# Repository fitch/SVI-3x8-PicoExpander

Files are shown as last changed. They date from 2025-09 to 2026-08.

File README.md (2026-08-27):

# SVI-3x8 PicoExpander

## Overview

The SVI-3x8 PicoExpander is a Raspberry Pico 2 W based expansion device for Spectravideo 318 and 328 computers.

The device emulates (when plugged into the SVI-3x8 expansion port):
 - **96 kB of additional RAM (BK22, BK31, BK32) to SVI-328**, to be used for example with BASIC SWITCH command or CP/M
 - **144 kB more RAM to SVI-318**, converting it to a SVI-328 and allowing games designed for SVI-328 to be run on a 318
 - **Disk emulation (.dsk)** so you can load and save disk images via Wi-Fi
 - **Cassette drive emulation (.cas)** with auto-running, allowing you to finally send and run .CAS images via Wi-Fi
 - **Support for 64 kB ROM game cartridges**, without using the game cartridge slot and finally fixing the 64 kB ROM support in SVI-328 MKII devices
 - **Save states** to save computer state and load it at later time, making it possible to save your progress in a game and continue later
 - **Remote launch** allowing you to pick up a game image from PC/Mac and launch it from the SVI via Wi-Fi
 - **Hard disk emulation** with server-based network backing, allowing CP/M hard disk images to be served over Wi-Fi

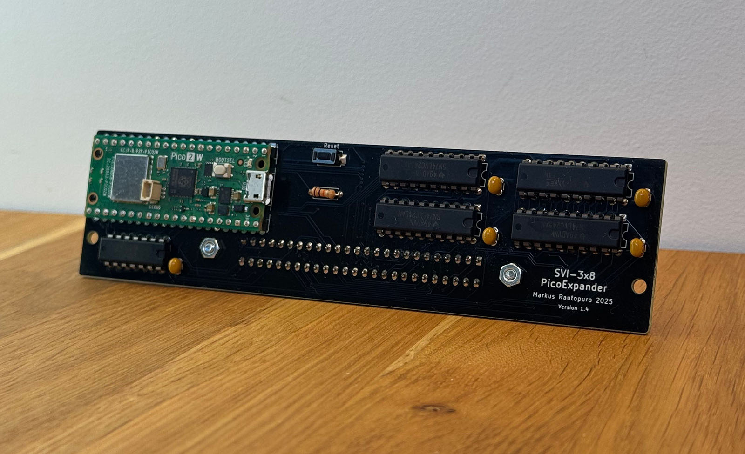
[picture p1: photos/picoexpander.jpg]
PicoExpander

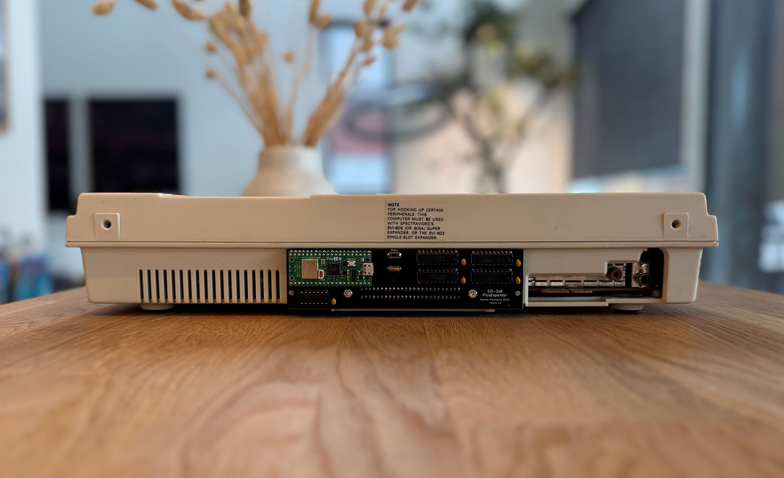
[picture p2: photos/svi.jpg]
SVI


## Limitations

Limitations of the current software (1.4.4):
 - Supports only one disk drive, two-disk drive support coming up

## The project

This repository will later include the full software and the hardware design later as open source. Now you can access the 1.4 PCB version in [pcb](pcb/) directory.

If you can't build one yourself, you can order an assembled version from [here](https://svi-328-dev.company.site/products/svi-3x8-picoexpander-1-4). Current shipping estimate in 1-4 weeks depending on the order volumes.

<b>Important note:</b>

This is ”bleeding edge” hardware, so it might not last 40 years as the SVI did. The Pico pins are used with level shifters and within the limits of the voltage thresholds, but the actual Pico CPU is running overclocked at 300 MHz (normally 150 MHz). This might cause the Pico to wear out sooner than Raspberry has designed it to. However, the Pico can be replaced on the board if needed.

Also, note that device is a prototype and therefore has very limited warranty: you can test it when it arrives and if you're not satisfied, we'll figure out if we ship a new one or you get your money back or something else. But everything else is at your own risk. If the device stops working after 3-12 months, you'll need to fix it yourself or get a new one.

## Quick Start

### 1. Flash the Firmware

When you've built the PCB you can flash the .UF2 file provided in the [release](release/) directory. For the assembled devices, the Pico has already been flashed with the latest firmware.

1. Disconnect PicoExpander from SVI
2. Hold the **BOOTSEL** button on the Pico W while connecting it to your computer via USB
3. The Pico will appear as a USB mass storage device
4. Copy the `.uf2` firmware file from the `release/` directory to the Pico USB drive. Wait until Pico disconnects (displays Disk Not Ejected Properly in macOS) and the green LED light turns on to signal that the firmware booted correctly.
5. Finally, remove the USB cable.

### 2. Install Node.js

The file server requires Node.js to run. This project includes an `.nvmrc` file specifying Node.js v22.20.0.

**macOS (using nvm):**

Install [nvm](https://github.com/nvm-sh/nvm) if you don't have it, then:
```bash
# Install and use the correct Node.js version
nvm install
nvm use
```

**Windows:**
Download and install from [nodejs.org](https://nodejs.org/)

### 3. Boot the SVI with PicoExpander

Place the PicoExpander into the expansion port of the SVI-318 or SVI-328. Boot SVI up.

You can return to the main menu in two ways:
- Press the **RESET button** on the PicoExpander briefly
- Press **CTRL + SHIFT + LEFT GRAPH + RIGHT GRAPH** simultaneously on the keyboard

If you need to reset the SVI, press the RESET button for at least 3 seconds.

### 4. Run the File Server

Start the server with a directory containing your disk images, ROMs, and cassette files:

```bash
node js/server.js ./images
```

The server will:
- Scan the directory for supported files (.rom, .dsk, .cas, .sta)
- Connect to the PicoExpander over Wi-Fi
- Serve files to the SVI-328 on demand

Press **H** in the server to see available commands.

## Documentation

For detailed documentation, see the `doc/` directory:

| Document | Description |
|---|---|
| [server.md](doc/server.md) | File server usage and interactive commands |
| [send_command.md](doc/send_command.md) | Command-line tool for scripting and automation |
| [hard-disk-emulation.md](doc/hard-disk-emulation.md) | Hard disk emulation setup and usage |
| [boot-sequence.md](doc/boot-sequence.md) | Technical details of the PicoExpander boot process |
| [io-ports.md](doc/io-ports.md) | I/O port reference for developers |
| [save-state-format.md](doc/save-state-format.md) | Save state file format specification |
| [development.md](doc/development.md) | Building the ROM and development setup |
| [pcb/README.md](pcb/README.md) | PCB design files, schematics overview, and parts list |

## Release Notes

See the latest changes in [v1.4.4 release notes](release/release-notes-1.4.4.md).

## License

Detailed licensing information is documented within the included [LICENSE](LICENSE) file.

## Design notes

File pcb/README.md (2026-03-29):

# SVI-3x8 PicoExpander PCB

## Overview

This directory contains the KiCad hardware design files for the SVI-3x8 PicoExpander and the SuperExpander adapter board.

## Projects

### PicoExpander (main board)

The main expansion board that connects to the SVI-3x8 expansion port via a 50-pin edge connector.

- **KiCad project:** [SVI-3x8-PicoExpander.kicad_pro](SVI-3x8-PicoExpander.kicad_pro)
- **Schematic:** [SVI-3x8-PicoExpander.kicad_sch](SVI-3x8-PicoExpander.kicad_sch)
- **PCB layout:** [SVI-3x8-PicoExpander.kicad_pcb](SVI-3x8-PicoExpander.kicad_pcb)
- **Schematics PDF:** [schematics.pdf](../photos/schematics.pdf)

### SuperExpander Adapter

A simple passive adapter board that allows the PicoExpander to be connected to the Spectravideo SuperExpander (SVI-605) instead of directly to the computer's expansion port.

- **KiCad project:** [SVI-3x8-PicoExpander-SuperExpander-adapter.kicad_pro](SVI-3x8-PicoExpander-SuperExpander-adapter.kicad_pro)
- **PCB layout:** [SVI-3x8-PicoExpander-SuperExpander-adapter.kicad_pcb](SVI-3x8-PicoExpander-SuperExpander-adapter.kicad_pcb)

### Gerber Files

Manufacturing-ready Gerber files are available in the [gerber/](gerber/) directory:

- [gerber/PicoExpander/](gerber/PicoExpander/) — Main board Gerbers
- [gerber/SuperExpander adapter/](gerber/SuperExpander%20adapter/) — Adapter board Gerbers

## Schematics Overview

The PicoExpander circuit consists of:

- **Raspberry Pi Pico 2 W (A1)** — The main microcontroller running the emulation firmware at 300 MHz. Connects to the SVI bus through level shifters and handles all emulation logic, Wi-Fi connectivity, and flash storage.

- **4x 74LVC245A level shifters (U1, U2, U4, U5)** — Bidirectional bus transceivers that translate between the SVI's 5V bus and the Pico's 3.3V logic levels:
  - **U5** — Data bus write (SVI → Pico, active during bus writes)
  - **U1** — Data bus read (Pico → SVI, active during bus reads)
  - **U2** — Lower address bus A0–A7
  - **U4** — Higher address bus A8–A15

- **74HC14 Schmitt trigger (U3, 7 gates used)** — Provides clean signal conditioning for active-low control signals from the SVI bus: `/RST`, `/ROMDIS`, `/RD`, `/WR`, `/MREQ`, `/P_AE` (address enable), and `/P_RD_DE`/`/P_WR_DE` (data direction enable).

- **50-pin edge connector (J1)** — Interfaces directly with the SVI-3x8 expansion bus, providing access to the full address bus, data bus, and control signals.

- **Reset button (SW1)** — Short press returns to the PicoExpander menu. Long press (3+ seconds) resets the SVI.

- **Pull-up resistor (R1, 10kΩ)** — Pull-up on the reset line.

- **Decoupling capacitors (C2–C5, 0.1μF)** — One per level shifter IC for power supply filtering.

## Parts List

| Ref | Qty | Description | DigiKey Part | DigiKey # |
|-----|-----|---|---|---|
| A1 | 1 | Raspberry Pi Pico 2 W (RP2350) | [SC1634](https://www.digikey.com/en/products/detail/raspberry-pi/SC1634/26241087) | 2648-SC1634-ND |
| U1, U2, U4, U5 | 4 | 74LVC245A — Bidirectional level shifter, 3.6V, 20-PDIP | [SN74LVC245AN](https://www.digikey.com/en/products/detail/texas-instruments/SN74LVC245AN/377483) | 296-8503-5-ND |
| U3 | 1 | 74HC14 — Hex Schmitt trigger inverter, 14-DIP | [SN74AHCT14N](https://www.digikey.com/en/products/detail/texas-instruments/SN74AHCT14N/375854) | 296-4674-5-ND |
| C2–C5 | 4 | 0.1μF ceramic capacitor, 50V, X7R, radial | [K104K15X7RF5TL2](https://www.digikey.com/en/products/detail/vishay-beyschlag-draloric-bc-components/K104K15X7RF5TL2/286538) | BC1084CT-ND |
| R1 | 1 | 10kΩ resistor, 1/4W, 1%, axial | [MFR-25FRF52-10K](https://www.digikey.com/en/products/detail/yageo/MFR-25FRF52-10K/14626) | 13-MFR-25FRF52-10KCT-ND |
| J1 | 1 | 50-pin (2x25) card edge connector, dual female, 0.100" pitch | [395-050-524-202](https://www.digikey.com/en/products/detail/edac-inc/395-050-524-202/1297302) | 395-050-524-202-ND |
| SW1 | 1 | Tactile push button switch, SPST-NO, 0.05A, 12V | [PTS636 SP43 LFS](https://www.digikey.com/product-detail/en/c-k/PTS636-SP43-LFS/CKN12304-ND/10071717) | CKN12304-ND |

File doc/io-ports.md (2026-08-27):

# I/O Ports Reference

This document describes the I/O ports used by the PicoExpander to communicate between the Z80 CPU and the Pico microcontroller.

## Table of Contents

- [Port Map Overview](#port-map-overview)
- [Pico Control Ports (0x13-0x18)](#pico-control-ports-0x13-0x18)
- [Cassette Emulation Ports (0x64-0x65)](#cassette-emulation-ports-0x64-0x65)
- [FDC Emulation Ports (0x30-0x38)](#fdc-emulation-ports-0x30-0x38)
- [Command Reference](#command-reference)
- [Appendix A: State Codes](#appendix-a-state-codes)
- [Appendix B: File Type Codes](#appendix-b-file-type-codes)
- [Appendix C: Status Response Codes](#appendix-c-status-response-codes)

---

## Port Map Overview

| Port Range  | Category | Description |
|---|---|---|
| 0x13-0x18 | Pico Control | Status, commands, data transfer, timers |
| 0x30-0x38 | FDC | Floppy disk controller emulation |
| 0x64-0x65 | Cassette | Tape emulation |
| 0x80-0x85 | VDP | Video Display Processor (see note below) |
| 0x88, 0x8C  | PSG | Programmable Sound Generator (see note below) |

> **Note:** VDP ports are used to read VDP register status for restoring the state after exiting the menu. PSG ports are read to enable preventing actual bank switching by using a fake register injection.

---

## Pico Control Ports (0x13-0x18)

### Port 0x13 - Command & Status

| Direction | Function | Description |
|---|---|---|
| Read | Pico State | Returns current Pico state (see [Appendix A](#appendix-a-state-codes)) |
| Write | Pico Command | Sends command to Pico (see [Command Reference](#command-reference)) |

### Port 0x14 - Data Transfer

| Direction | Function | Description |
|---|---|---|
| Read | Pico Data  | Reads data from Pico (context depends on last command) |
| Write | Pico Data  | Writes data to Pico (context depends on last command) |

Data format and interpretation depend on the command previously sent to port 0x13.

### Port 0x15 - Timer High Byte

| Direction | Function | Description |
|---|---|---|
| Read | Timer High | Returns high 8 bits of timestamp counter |
| Write | Timer Reset  | Resets the timestamp counter to 0 |

### Port 0x16 - Timer Low Byte

| Direction | Function | Description |
|---|---|---|
| Read | Timer Low  | Returns low 8 bits of timestamp counter |

**Timer Details:** 16-bit microsecond counter (0-65535 μs, wraps in ~65.5ms). Read 0x15 first (high byte), then 0x16 (low byte). Write any value to 0x15 to reset. Increments at 1 MHz from Pico hardware timer.

### Port 0x17 - Debug Output

| Direction | Function | Description |
|---|---|---|
| Write | Debug | Writes debug values to hardware log |

### Port 0x18 - Status Flags

| Direction | Function | Description |
|---|---|---|
| Read | Status Flags | Network, file serving, and boot status |

**Bit Layout:**
```
┌─────┬─────┬─────┬─────┬─────┬─────┬─────┬─────┐
│  7  │  6  │  5  │  4  │  3  │  2  │  1  │  0  │
├─────┼─────┼─────┴─────┴─────┼─────┴─────┴─────┤
│ RSV │BOOT │  File Status    │ Network Status  │
└─────┴─────┴─────────────────┴─────────────────┘
```

#### Bits 0-2: Network Connection Status

| Value | Description |
|---|---|
| 0 | Not connected to Wi-Fi, idle |
| 1 | Connecting to Wi-Fi |
| 2 | Error connecting |
| 3 | Connected to Wi-Fi |

#### Bits 3-5: File Serving Status

| Value | Description |
|---|---|
| 0 | PC/Mac not connected to Pico |
| 1 | PC/Mac connected, file list not yet available |
| 2 | Pico busy updating file list |
| 3 | File serving active and ready for commands |
| 4 | PC/Mac sending an image, file serving busy |
| 5 | Updated file list available (returns to 3 after requesting file count) |

#### Bit 6: Short Press Boot Flag

| Value | Description |
|---|---|
| 0 | No short press detected |
| 1 | Reset button was pressed shortly (clears to 0 when register is read) |

#### Bit 7: Reserved

Reserved for future use.

---

## Cassette Emulation Ports (0x64-0x65)

### Port 0x64 - Cassette Data

| Direction | Function | Description |
|---|---|---|
| Read | Cassette Data | Reads next byte from tape buffer |

### Port 0x65 - Cassette Status & Control

| Direction | Function | Description |
|---|---|---|
| Read | Cassette Status  | Current tape status |
| Write | Cassette Control | Tape control commands |

#### Read Values (Status)

| Value | Description |
|---|---|
| 0x00  | No tape loaded  |
| 0x01  | Tape at start |
| 0x02  | Tape at end |
| 0x03  | Tape in middle  |
| 0xFF  | Tape not ready  |

#### Write Values (Control)

| Value | Command |
|---|---|
| 0x01  | Rewind tape |
| 0x02  | Start write (not yet implemented)  |
| 0x03  | Stop write (not yet implemented) |

---

## FDC Emulation Ports (0x30-0x38)

The PicoExpander emulates a WD1793-compatible floppy disk controller. Disk images are stored in PSRAM and transferred to/from the PC/Mac file server as needed.

### Port Summary

| Port | Direction | Name | Description |
|---|---|---|---|
| 0x30 | Read | Controller Status | FDC status register |
| 0x30 | Write | Controller Command | FDC command register |
| 0x31 | Read/Write| Track Register | Current track number (0-79) |
| 0x32 | Read/Write| Sector Register | Current sector number |
| 0x33 | Read/Write| Data Register | Data transfer byte |
| 0x34 | Read | Drive Status | Data ready and interrupt status |
| 0x34 | Write | Drive Select | Drive selection (bit 0 = drive 0, bit 1 = drive 1) |
| 0x38 | Write | Density/Side Select | Bit 0 = density, bit 1 = side |

### Controller Commands (Port 0x30 Write)

| Command | Hex | Description |
|---|---|---|
| Restore | 0x0x  | Seek to track 0 |
| Seek | 0x1x  | Seek to track specified in data register |
| Step In | 0x5x  | Step toward higher track numbers |
| Step Out| 0x7x  | Step toward lower track numbers |
| Read | 0x8x  | Read sector |
| Write | 0xAx  | Write sector |
| Force Int| 0xDx | Force interrupt, abort current operation |

### Drive Status (Port 0x34 Read)

| Value | Meaning |
|---|---|
| 0x00  | Track data not ready (loading) |
| 0x40  | Data ready for transfer |
| 0x80  | INTRQ (operation complete) |

### Notes

- Track data is cached in PSRAM for fast access
- When the track changes, the Pico fetches the new track data in the background
- Sector size is 128 bytes on track 0/side 0, 256 bytes elsewhere
- Supports 40-track and 80-track disk formats

---

## Command Reference

Commands are sent by writing to port 0x13. Data is exchanged via port 0x14.

### Command Summary

| Code | Name | Category | Description |
|---|---|---|---|
| 0x01 | Write Wi-Fi Credentials | Configuration | Enter Wi-Fi credentials write mode |
| 0x02 | Write Save State | Configuration | Enter save state filename write mode |
| 0x03 | Terminate Write | Configuration | End write mode and process data |
| 0x04 | Write BIOS | Configuration | Enter BIOS write mode (prepare mode only)|
| 0x05 | Write 32KB ROM | Configuration | Enter ROM write mode (prepare mode only) |
| 0x06 | Stop Serving Prepare | Configuration | Stop serving prepare.asm, enable HW BIOS |
| 0x07 | Dump Disk | Configuration | Capture real disk contents into Pico |
| 0x10 | Boot with Cassette | Boot | Boot BIOS with cassette emulation |
| 0x11 | Boot Normal | Boot | Boot normal BIOS |
| 0x13 | Erase Credentials | Configuration | Erase stored Wi-Fi credentials |
| 0x14 | Clear Hardware Log | Debug | Clear Pico hardware log |
| 0x20 | Get File Count | File Server | Get count of available files |
| 0x21 | Get File Info | File Server | Get information about a specific file |
| 0x22 | Request File | File Server | Request file transfer from PC/Mac |
| 0x30 | Disable Short Press | Configuration | Disable short press boot (default) |
| 0x31 | Enable Short Press | Configuration | Enable short press boot |
| 0x40 | Set File Filter | File Server | Set file type filter |
| 0x50 | Access Configuration | Configuration | Read/write persistent configuration |
| 0x51 | Feature Flags | Configuration | Enable/disable PicoExpander features |
| 0x52 | Media Control | Configuration | Eject media or copy BK11 to cartridge |

---

### Configuration Commands

#### 0x01 - Write Wi-Fi Credentials

Enters Wi-Fi credentials write mode for storing network settings.

**Protocol:**
```
1. OUT 0x13, 0x01          ; Enter credentials write mode
2. OUT 0x14, <ssid bytes>  ; Write 32 bytes SSID
   OUT 0x14, <pass bytes>  ; Write 63 bytes password
3. OUT 0x13, 0x03          ; Terminate and store
```

**Data Format:**
- Bytes 0-31: SSID (32 bytes, null-padded)
- Bytes 32-94: Password (63 bytes, null-padded)
- Maximum total: 256 bytes

#### 0x02 - Write Save State Filename

Enters save state write mode to specify a filename for save/load operations.

**Protocol:**
```
1. OUT 0x13, 0x02          ; Enter save state write mode
2. OUT 0x14, <filename>    ; Write filename bytes (without .sta extension)
3. OUT 0x13, 0x03          ; Terminate and initiate download
```

**Behavior:**
- Terminate (0x03) stores filename and immediately requests download from PC
- Empty filename defaults to `"saved_state.sta"`
- Omitting new filename reuses previous filename

#### 0x03 - Terminate Write Mode

Ends any active write mode (0x01, 0x02, 0x04, 0x05) and processes the data.

#### 0x06 - Stop Serving Prepare

Used only during prepare mode. Signals the Pico to stop serving prepare.asm code from lower bank and enable the hardware BIOS ROM via ROMDIS. After this command, lower bank reads will be served by the actual hardware BIOS ROM instead of the Pico.

**Protocol:**
```
OUT 0x13, 0x06             ; Stop serving prepare code, enable HW BIOS ROM
```

This command is used internally by prepare.asm after it has copied itself to RAM and jumped to the upper bank. It allows prepare.asm to read data from the hardware BIOS ROM.

#### 0x07 - Dump Disk

Captures the contents of a real floppy disk drive and stores the data into the Pico's flash memory. This allows creating disk images from physical disks. The Z80 reads data from the real FDC and transfers it to the Pico byte by byte.

**Protocol:**
```
OUT 0x13, 0x07             ; Enter disk dump mode
OUT 0x14, 0x00             ; Select drive 0 (resets write buffer index to 0)
OUT 0x14, <byte>           ; Write disk data byte (sector buffer contents)
OUT 0x14, <byte>           ; Write disk data byte
...                        ; Continue for all sectors on all tracks/sides
OUT 0x13, 0x03             ; Terminate and flush remaining data to flash
```

| Value | Drive |
|---|---|
| 0 | Drive 0  |

**Behavior:**
- Drive selection (first data byte) resets the dump write index and flash pointer to 0
- Data is written byte by byte into an 8192-byte double-buffer (2 × 4096)
- When each 4096-byte half fills, it is flashed to the disk area automatically
- On terminate (0x03), any remaining partial buffer is padded with 0xFF and flushed
- After completion, `disk_size` is set to the total number of bytes written

**Maximum size:** 346,112 bytes (fits a 40-track double-sided disk image).

#### 0x50 - Access Stored Configuration

Provides access to 16 bytes of persistent configuration in flash memory.

**Protocol:**
```
; Reading
OUT 0x13, 0x50             ; Enter config mode
IN  A, (0x14)              ; Read byte 0
IN  A, (0x14)              ; Read byte 1
...                        ; Continue for 16 bytes

; Writing
OUT 0x13, 0x50             ; Enter config mode
OUT 0x14, <byte0>          ; Write byte 0
OUT 0x14, <byte1>          ; Write byte 1
...                        ; Continue for 16 bytes (auto-saves)
```

#### 0x51 - Feature Flags

Enables or disables PicoExpander features at runtime.

**Protocol:**
```
; Reading current flags
OUT 0x13, 0x51             ; Enter feature flags mode
IN  A, (0x14)              ; Read feature flags byte

; Writing new flags
OUT 0x13, 0x51             ; Enter feature flags mode
OUT 0x14, <flags>          ; Write feature flags byte
```

**Bit Layout:**
```
┌─────┬─────┬─────┬─────┬─────┬─────┬─────┬─────┐
│  7  │  6  │  5  │  4  │  3  │  2  │  1  │  0  │
├─────┴─────┴─────┴─────┴─────┴─────┼─────┼─────┤
│           Reserved (0)            │TAPE │ FDC │
└───────────────────────────────────┴─────┴─────┘
```

| Bit | Name | Description |
|-----|---|---|
| 0 | FDC  | FDC emulation: 0 = disabled, 1 = enabled |
| 1 | TAPE | Patch BIOS ROM with tape emulation code: 0 = not patched, 1 = patched |
| 2-7 | — | Reserved for future use (always read as 0) |

> **Note:** On cold boot, feature flags default to 0x00 (all features disabled). Software must explicitly enable FDC and/or tape emulation as needed.

#### 0x52 - Media Control

Controls media slots: eject (zero out) loaded media or copy the real BK11 ROM to the cartridge slot.

**Protocol:**
```
OUT 0x13, 0x52             ; Enter media control mode
OUT 0x14, <operation>      ; Execute operation
```

**Bit Layout:**
```
┌─────┬─────┬─────┬─────┬─────┬─────┬─────┬─────┐
│  7  │  6  │  5  │  4  │  3  │  2  │  1  │  0  │
├─────┴─────┼─────┼─────┼─────┼─────┼─────┼─────┤
│ Reserved  │BOOT │BK11 │TAPE │CART │DSK1 │DSK0 │
└───────────┴─────┴─────┴─────┴─────┴─────┴─────┘
```

| Bit | Name | Description |
|-----|---|---|
| 0 | DSK0 | Eject Disk 0: mark disk 0 as not loaded |
| 1 | DSK1 | Eject Disk 1: mark disk 1 as not loaded |
| 2 | CART | Eject Cartridge: zero out cartridge ROM memory |
| 3 | TAPE | Eject Tape: mark tape as not loaded |
| 4 | BK11 | Load BK11 to Cartridge ROM |
| 5 | BOOT | Load Bootsector to Cartridge ROM |
| 6-7 | — | Reserved (always 0) |

**Operations:**

| Bit | Code | Operation | Description |
|-----|---|---|---|
| 0 | 0x01 | Eject Disk 0 | Mark disk 0 as not loaded |
| 1 | 0x02 | Eject Disk 1 | Mark disk 1 as not loaded |
| 2 | 0x04 | Eject Cartridge ROM| Zero out cartridge ROM memory |
| 3 | 0x08 | Eject Tape | Mark tape as not loaded |
| 4 | 0x10 | Load BK11 to Cartridge ROM | Copy stored BK11 data to cartridge ROM emulation |
| 5 | 0x20 | Load Bootsector to Cartridge ROM | Copy bootsector code to cartridge ROM so BIOS boots it |

**Notes:**
- Operations can be combined as a bitmask (e.g., 0x03 ejects both disks)
- Eject Cartridge clears the memory area with `0xff`s
- Eject Disk/Tape sets size to 0 (flash contents unchanged)
- During boot, the prepare phase (see `prepare.asm`) detects if a real cartridge is attached and dumps its first 32 KB into the BK11 array. The 0x10 operation copies this BK11 data to the ROM_CARTRIDGE array, enabling cartridge emulation using the original physical cartridge's contents.
- The 0x20 operation copies the bootsector code to ROM_CARTRIDGE, allowing BIOS to boot from the cartridge which then boots the launcher.

---

### Boot Commands

#### 0x10 - Boot BIOS with Cassette Emulation

Boots the SVI BIOS with cassette tape emulation enabled.

#### 0x11 - Boot Normal BIOS

Boots the SVI BIOS normally without cassette emulation.

#### 0x30/0x31 - Short Press Boot Control

- **0x30**: Disable short press boot (default behavior)
- **0x31**: Enable short press boot

When enabled, a short press of the reset button triggers boot flag (bit 6 of port 0x18).

---

### File Server Commands

These commands interact with the PC/Mac file server via Wi-Fi.

#### 0x20 - Get File Count

Returns the number of files available matching the current filter.

**Protocol:**
```
OUT 0x13, 0x20             ; Send command
OUT 0x14, <filter>         ; File type filter (0xFF = use previous)
poll:
IN  A, (0x14)              ; Read status
CP  0x80
JR  Z, poll                ; 0x80 = not ready, poll again
; A = 0x00 (success) or 0x01 (failed)
IN  A, (0x14)              ; Low byte of count
IN  A, (0x14)              ; High byte of count
```

**Filter Values:**
| Value | Filter |
|---|---|
| 0x00  | No filter (all) |
| 0x01  | Tape images only |
| 0x02  | ROM images only |
| 0x03  | Disk images only |
| 0x04  | Save states only |
| 0xFF  | Use previous filter |

**Note:** If port 0x18 showed status 5 (updated file list), it returns to 3 (ready) after this command.

#### 0x21 - Get File Information

Returns type and filename for a specific file index.

**Protocol:**
```
OUT 0x13, 0x21             ; Send command
OUT 0x14, <index_lo>       ; Low byte of file index
OUT 0x14, <index_hi>       ; High byte of file index
poll:
IN  A, (0x14)              ; Read status
CP  0x80
JR  Z, poll                ; 0x80 = not ready
; A = 0x00 (success) or 0x01 (failed)
IN  A, (0x14)              ; File type (see Appendix B)
; Read 30 bytes: ASCII filename, null-padded
```

**Response:**
- Byte 0: Status code
- Byte 1: File type (see [Appendix B](#appendix-b-file-type-codes))
- Bytes 2-31: Filename (30 ASCII bytes, null-padded)

#### 0x22 - Request File Send

Requests the PC/Mac to send a specific file to the Pico.

**Protocol:**
```
OUT 0x13, 0x22             ; Send command
OUT 0x14, <index_lo>       ; Low byte of file index
OUT 0x14, <index_hi>       ; High byte of file index
poll:
IN  A, (0x14)              ; Read status
CP  0x80
JR  Z, poll
; A = 0x00 (success) or 0x01 (failed)
```

#### 0x40 - Set File Type Filter

Sets the file type filter for subsequent file operations.

**Protocol:**
```
OUT 0x13, 0x40             ; Send command
OUT 0x14, <filter>         ; Filter value (see 0x20 filter table)
```

---

### Debug Commands

#### 0x14 - Clear Pico Hardware Log

Clears the Pico's hardware debug log.

---

## Appendix A: State Codes

State codes returned when reading port 0x13.

### Normal States (0x64-0x75)

| Dec | Hex  | State |
|-----|---|---|
| 100 | 0x64 | Waiting for credentials |
| 101 | 0x65 | Credentials received |
| 102 | 0x66 | Credentials stored |
| 103 | 0x67 | Wi-Fi connecting |
| 104 | 0x68 | Wi-Fi connected |
| 105 | 0x69 | Wi-Fi error |
| 106 | 0x6A | Client connected |
| 107 | 0x6B | Receiving ROM |
| 108 | 0x6C | ROM ready |
| 109 | 0x6D | Receiving disk |
| 110 | 0x6E | Disk ready |
| 112 | 0x70 | Client disconnected |
| 113 | 0x71 | Receiving tape |
| 114 | 0x72 | Tape ready |
| 115 | 0x73 | Boot BIOS |
| 116 | 0x74 | Receiving BK3X |
| 117 | 0x75 | BK3X ready |

### Process States (0xC8-0xC9)

| Dec | Hex  | State |
|-----|---|---|
| 200 | 0xC8 | Injecting boot |
| 201 | 0xC9 | Boot success |

### Error States (0xE6+)

| Dec | Hex  | State |
|-----|---|---|
| 230 | 0xE6 | Wi-Fi bad auth |
| 231 | 0xE7 | Wi-Fi timeout  |
| 252 | 0xFC | Boot fail |
| 253 | 0xFD | Memory error |
| 254 | 0xFE | Error |
| 255 | 0xFF | Unknown |

---

## Appendix B: File Type Codes

File type encoding: lower 4 bits = main type, upper 4 bits = subtype.

| Code | Main Type | Subtype | Description |
|---|---|---|---|
| 0x11 | Tape (1) | 1 | .CAS cassette image |
| 0x12 | ROM (2) | 1 | 32 KB SVI-3x8 ROM (lower bank) |
| 0x22 | ROM (2) | 2 | 64 KB SVI-3x8 ROM (requires ROMEN0/1) |
| 0x13 | Disk (3) | 1 | Disk BASIC, 40 track single-sided |
| 0x23 | Disk (3) | 2 | Disk BASIC, 40 track double-sided |
| 0x33 | Disk (3) | 3 | Disk BASIC, 80 track single-sided |
| 0x43 | Disk (3) | 4 | CP/M, 40 track single-sided |
| 0x53 | Disk (3) | 5 | CP/M, 40 track double-sided |
| 0x63 | Disk (3) | 6 | CP/M, 80 track single-sided (not implemented)  |
| 0x14 | Savestate (4)| 1 | SVI-3x8 Save State |

**Main Type Values (for filtering):**
| Value | Type |
|---|---|
| 1 | Tape |
| 2 | ROM |
| 3 | Disk |
| 4 | Savestate |

---

## Appendix C: Status Response Codes

Common status codes returned by file server commands.

| Code | Meaning |
|---|---|
| 0x00 | Success, data available |
| 0x01 | Failed, cannot recover |
| 0x80 | Not ready, poll again |

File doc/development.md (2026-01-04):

# Development

## Building the ROM

```bash
cd rom
make
```

**Required assemblers:**
- [rasm](https://github.com/EdouardBERGE/rasm)
- [sjasmplus](https://github.com/z00m128/sjasmplus)

## Building on Windows

```bash
cd rom
make.bat
```

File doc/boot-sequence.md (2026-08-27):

# Boot Sequence

When the SVI-328 is powered on with the PicoExpander installed, the following boot sequence occurs.

There are two distinct bootstrap phases that are easy to confuse, so they are
called out explicitly below:

- **PREPARE** — a one-time, low-level bootstrap that installs the emulated BIOS
  (and snapshots a real cartridge, if present). It runs entirely from the
  emulated `BIOS`/`RAM0` buffers and never touches `ROM_CARTRIDGE`.
- **ROM_CARTRIDGE launcher boot** — how the PicoExpander menu is started: a tiny
  bootstrap is placed in the emulated cartridge slot (`ROM_CARTRIDGE`) so the
  SVI's native cartridge-autostart runs it, and it jumps into the real launcher
  living in `RAM4` (BK4X).

## 1. Initial Hardware State (Power-On)

- The PicoExpander holds both **RAMDIS** and **ROMDIS** signals **LOW** (disabled).
- This disables the SVI-328's internal boot ROM and internal RAM.
- The Z80 CPU starts executing from address `0x0000`, with the PicoExpander
  providing all code and memory.

## 2. PicoExpander Initialization (Core 1)

The PicoExpander's second core (`core1_entry()` in
[svi-328-expander-bus.c](../pico/c/svi-328-expander-bus.c)) initializes the system:

- Disables interrupts and gives Core 1 priority on the bus.
- Calls `launcher_initialization()`, which:
  - Copies `LAUNCHER_BK4X` (~48 KB) into **RAM4** (the BK41/BK42 banks) — this is
    the actual launcher menu program.
  - Writes the Pico's unique device ID into `RAM4` at `DEVICE_ID_ADDRESS`.
- Calls `boot_initialization()`, which:
  - Ejects the cartridge (clears `ROM_CARTRIDGE`) so a stale/loaded ROM doesn't
    auto-boot.
  - Marks disk and tape as empty.
  - Sets the initial banks: lower bank = `BIOS`, upper bank = `RAM0` (BK02).
- Sets `inject_type = INJECT_TYPE_PREPARE`.
- **Copies the [PREPARE code](../pico/asm/prepare.asm) into the `BIOS` buffer** —
  this is what the Z80 will execute first.

Core 1 then runs a dispatch loop that calls, based on `inject_type`:

| `inject_type` | Function | Purpose |
| --- | --- | --- |
| `INJECT_TYPE_PREPARE` | `prepare()` | One-time bootstrap (section 3) |
| `INJECT_TYPE_NONE` | `floppy_and_ram_emulation()` | Normal full emulation (section 4) |
| `INJECT_TYPE_BOOT` | `inject_boot()` | Re-boot into launcher (section 6) |

## 3. PREPARE Phase Execution

The `prepare()` function runs while `inject_type == INJECT_TYPE_PREPARE`.

### What the Z80 CPU sees

- The PicoExpander initially feeds `0xC7` (RST 00h) instructions until the CPU
  reads from address `0x0000`.
- Once at `0x0000`, the PicoExpander serves the
  **[PREPARE.ASM](../pico/asm/prepare.asm)** code from the `BIOS` buffer for the
  lower bank (`0x0000`–`0x7FFF`), while `serve_prepare` is `true`.
- Upper-bank (`0x8000`–`0xFFFF`) reads/writes are served from `RAM0`.

> **Note:** `prepare()` never reads, writes, or executes `ROM_CARTRIDGE`. The
> code runs from the `BIOS` buffer (lower bank) and then from `RAM0` (upper bank,
> after it relocates itself — see below).

### What PREPARE.ASM does

1. Configures PSG register 15 for bank selection (CAPS LOCK off, no memory banks
   enabled initially).
2. **Relocates itself** from the lower bank to RAM at `0x8000` and continues
   executing there (from `RAM0`).
3. Sends `PE_COMMAND_STOP_SERVING_PREPARE` (`0x06`) to port `0x13`. The
   PicoExpander stops serving the lower bank and drops **/ROMDIS LOW = 0**, so the
   real hardware drives the lower bank.
4. Checks for a real cartridge (CART signature at address 0). **If present**, it
   sends `PE_WRITE_32KB_ROM` (`0x05`) then streams the cartridge's 32 KB out port
   `0x14`; the PicoExpander captures those bytes into the `BK11` buffer.
5. Sends `PE_WRITE_BIOS` (`0x04`) to port `0x13` and streams the BIOS image out
   port `0x14`, which the PicoExpander stores into the emulated `BIOS` buffer.
6. Sends `PE_WRITE_TERMINATE` (`0x03`); on terminate of the BIOS write the
   PicoExpander raises **/ROMDIS** back and sets `inject_type = INJECT_TYPE_NONE`,
   switching to the emulated BIOS.
7. Performs floppy-disk-controller detection and reports the result via
   `PE_COMMAND_FEATURE_FLAGS` (`0x51`).
8. Sends `PE_COMMAND_MEDIA_CONTROL` (`0x52`) with value `0x20`
   (`LOAD_BOOTSECTOR_TO_CARTRIDGE`), which copies the 45-byte
   `LAUNCHER_BOOTSECTOR` into `ROM_CARTRIDGE` (see section 5).
9. Jumps to address `0x7B64` in the (now PicoExpander-hosted) BIOS to continue the
   normal cold-start sequence.

## 4. Normal Emulation Mode

Once `inject_type == INJECT_TYPE_NONE`, the dispatch loop calls
`floppy_and_ram_emulation()` on Core 1. The PicoExpander now fully emulates:

- **Memory banks** via a lookup table indexed by PSG register 15
  (`initialize_bank_lookup_table`). Each configuration maps a lower and upper
  bank pointer plus a "ROM?" flag; writes to ROM banks are dropped:
  - Cartridge: `ROM_CARTRIDGE` (BK11 low / BK12 high), read-only.
  - BIOS: `BIOS`, read-only.
  - RAM banks: `RAM0` (BK02), `RAM2` (BK21/22), `RAM3` (BK31/32), `RAM4` (BK41/42).
- **Floppy disk controller**: FDC I/O ports `0x30`–`0x38`.
- **Cassette tape emulation**: I/O ports `0x64`–`0x65`.
- **Video Display Processor (VDP)**: I/O ports `0x80`, `0x81`, `0x84`, `0x85`.
- **Programmable Sound Generator (PSG)**: I/O ports `0x88`, `0x8C`.
- **Custom PicoExpander control ports**: `0x13`–`0x18`.

## 5. ROM_CARTRIDGE Launcher Boot

The PicoExpander menu is **not** served as a floppy boot sector. Instead it uses
the SVI's native cartridge-autostart:

- During PREPARE (step 8) the 45-byte
  [`LAUNCHER_BOOTSECTOR`](../pico/asm/launcher_bootsector.asm) is copied into the
  emulated cartridge slot, `ROM_CARTRIDGE[0..45]`, with the cartridge selected.
- The BIOS cold start finds a cartridge present and runs it.
- The bootsector code:
  - Relocates itself to `0xC000` and continues executing there.
  - Selects **BK41 (RAM4)** + BK02 via PSG register 15.
  - Sends `PE_COMMAND_MEDIA_CONTROL` (`0x52`) value `0x04`
    (`EJECT_CARTRIDGE`) — this **clears the entire 64 KB `ROM_CARTRIDGE`**,
    removing the bootsector once it is no longer needed.
  - Jumps to address `0x0003`, which is now in `RAM4` (BK41) where `LAUNCHER_BK4X`
    was copied during initialization.
- The launcher menu code in `RAM4` takes control and displays the PicoExpander menu.

> **Important:** because the launcher bootstrap **wipes `ROM_CARTRIDGE`** on every
> boot, `ROM_CARTRIDGE` cannot be used to hold anything that must persist across
> the launcher start (e.g. a captured cartridge). That is why the real-cartridge
> capture (step 4) uses a separate `BK11` buffer.

## 6. Re-Booting Into the Launcher (Menu Exit)

After a game/program has been running, the system returns to the launcher via
`inject_boot()` (triggered by the launcher's boot request / the server `boot`
command). This does **not** repeat the PREPARE phase; it:

- Re-runs `launcher_initialization()` and `boot_initialization()`.
- Calls `load_bootsector_to_cartridge()` to place the launcher bootsector back
  into `ROM_CARTRIDGE`.
- Pulses **RST** and injects the `INJECTBOOT` stub so the CPU restarts and runs
  the cartridge bootstrap again (section 5), landing back in the `RAM4` launcher.

## Memory Bank Reference

| Buffer | Size  | Role |
| --- | ----- | --- |
| `BIOS` | 32 KB | Emulated BASIC BIOS ROM (lower bank); PREPARE runs here first |
| `ROM_CARTRIDGE` | 64 KB | Cartridge slot (BK11 low / BK12 high); holds the launcher bootsector transiently; wiped on launcher boot |
| `RAM0` | 32 KB | BK02 (default upper RAM) |
| `RAM2` | 64 KB | BK21 / BK22 |
| `RAM3` | 64 KB | BK31 / BK32 |
| `RAM4` | 64 KB | BK41 / BK42 — hosts the launcher (`LAUNCHER_BK4X`) |
| `BK11` | 32 KB | Capture buffer for a real cartridge snapshot (see PREPARE step 4) |

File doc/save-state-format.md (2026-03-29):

# Save State File Format

Save state files (`.sta`) capture the machine state for later restoration. The file format includes a header followed by memory bank data.

## File Header (32 bytes)

| Offset | Size | Description |
|---|---|---|
| 0-20 | 21 bytes | Magic string: `"PicoExpanderSaveState"` |
| 21 | 1 byte | Version number (`0x01`) |
| 22 | 1 byte | Reserved (filled with `0x00`) |
| 23 | 1 byte | Bank configuration (see below) |
| 24-31 | 8 bytes | Reserved (filled with `0x00`) |

## Bank Configuration Byte

The bank configuration byte at offset 23 specifies which memory banks are included in the save state file. Each bit corresponds to a specific bank:

| Bit | Bank | Description |
|-----|---|---|
| 0 | BK01 | RAM0 lower 32KB |
| 1 | BK02 | RAM0 upper 32KB |
| 2 | BK11 | RAM1 lower 32KB |
| 3 | BK12 | RAM1 upper 32KB |
| 4 | BK21 | RAM2 lower 32KB |
| 5 | BK22 | RAM2 upper 32KB |
| 6 | BK31 | RAM3 lower 32KB |
| 7 | BK32 | RAM3 upper 32KB |

### Example Bank Configurations

| Value | Binary | Banks Included | Description |
|---|---|---|---|
| 0x02 | 0b00000010 | BK02 | 32KB save state |
| 0x12 | 0b00010010 | BK02 + BK21 | 64KB save state |
| 0x32 | 0b00110010 | BK02 + BK21 + BK22 | 96KB save state |
| 0xF2 | 0b11110010 | BK02 + BK21 + BK22 + BK31 + BK32 | 160KB save state |

## Data Layout

After the 32-byte header, the data is stored with RAM4 first, followed by banks in order according to the bank configuration byte:

1. **VRAM (0x0000-0x3FFF)**: 16,384 bytes - Always present
2. **Device register area**: 64 bytes - Always present
3. **BK01**: 32,768 bytes - Present if bit 0 is set
4. **BK02**: 32,768 bytes - Present if bit 1 is set
5. **BK11**: 32,768 bytes - Present if bit 2 is set
6. **BK12**: 32,768 bytes - Present if bit 3 is set
7. **BK21**: 32,768 bytes - Present if bit 4 is set
8. **BK22**: 32,768 bytes - Present if bit 5 is set
9. **BK31**: 32,768 bytes - Present if bit 6 is set
10. **BK32**: 32,768 bytes - Present if bit 7 is set

## Example File Sizes

The file size is calculated as: `32 + 16,384 + 64 + (number_of_banks × 32,768)` bytes.

| Banks | Header | Data | Total File Size |
|---|---|---|---|
| 1 bank | 32 bytes | 49,216 bytes | 49,248 bytes |
| 2 banks | 32 bytes | 81,984 bytes | 82,016 bytes |
| 3 banks | 32 bytes | 114,752 bytes | 114,784 bytes |
| 5 banks | 32 bytes | 180,288 bytes | 180,320 bytes |

## Usage

From the server.js interactive interface, press **0** to capture the current machine state. The save state will be saved to `saved_state.sta` in the current directory.

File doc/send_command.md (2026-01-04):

# send_command.js - Command-Line Interface

A standalone CLI tool for sending individual commands to the PicoExpander.

## Usage

```bash
node js/send_command.js <command> <path/to/file> [options]
```

## Available Commands

### File Loading Commands

- **`load_rom <path/to/romfile.rom>`**  
  Upload a ROM file (2KB, 16KB, 32KB, 48KB, or 64KB) to the SVI-328. The ROM will be inserted into the cartridge slot.

- **`load_disk <path/to/diskimage.dsk>`**  
  Upload a disk image (172032 or 346112 bytes) to the PicoExpander for floppy disk emulation.

- **`load_cas <path/to/file.cas>`**  
  Upload a cassette tape file (max 524KB) for cassette emulation.

- **`load_bk4x <path/to/romfile.rom>`**  
  Upload a BK31/BK32 launcher ROM file to the PicoExpander's memory banks.

### Boot Commands

- **`launcher`**  
  Reboot the SVI-328 to the PicoExpander launcher menu.

### Logging Commands

- **`get_log`**  
  Retrieve and display both text and hardware logs from the PicoExpander.

- **`get_text_log`**  
  Retrieve and display only the text log from the PicoExpander.

- **`get_hardware_log`**  
  Retrieve and display only the hardware log from the PicoExpander, including PSG register access and memory bank control information.

## How It Works

1. Broadcasts a UDP discovery message to find the PicoExpander on the local network
2. Establishes a TCP connection on port 4242
3. Executes the requested command
4. Closes the connection and exits

## Difference from server.js

While `send_command.js` is designed for one-off commands (scripts/automation), `server.js` provides:
- A persistent file serving system that the PicoExpander can query
- Interactive file selection from the parsed catalog (not raw filesystem)
- Smart file filtering by type (ROM, disk, cassette)
- Metadata extraction and display
- Automatic reconnection on connection loss
- Watch mode for file changes

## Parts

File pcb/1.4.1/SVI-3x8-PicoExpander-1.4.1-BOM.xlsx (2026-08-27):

Comment | Designator | Footprint | JLCPCB Part #（optional）
74LVC245A | U4,U2,U1,U5 | DIP-20_W7.62mm | C2869324
0.1uF | C4,C2,C3,C5,C1 | C_Disc_D3.0mm_W1.6mm_P2.50mm | C882438
74HC14 | U3 | DIP-14_W7.62mm | C2869324
Raspberry Pi Pico 2 W | A1 | RaspberryPi_Pico_Common_Unspecified | C42394205
10K | R1 | R_Axial_DIN0207_L6.3mm_D2.5mm_P7.62mm_Horizontal | C2649453

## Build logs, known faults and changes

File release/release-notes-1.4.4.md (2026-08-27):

# SVI-3x8 PicoExpander v1.4.4 Release Notes

## New Features
- **New realtime protocol** — The custom 10-byte header protocol has been replaced with a layered design
- **Streamed logging** — Text and hardware logs stream to the server over a dedicated log channel with level filtering and a boot ring buffer, replacing the old dump-on-demand log feature
- **PCB 1.4.1** — New board revision added (it's a little bit wider), and the `pcb/` tree restructured so each revision lives in its own directory

## Improvements
- **Memory headroom** — BK11 bank dropped, RAM3 restored, and the hardware log snapshot removed to cut log size
- **Wi-Fi robustness** — Power saving disabled, heartbeat kill switch given a retry and a longer delay, and `wifi.c` restructured with dead code removed
- **File server operations** — File server requests and Wi-Fi operations reorganised; redundant BK4X save command and an extra tape data fetch removed
- **Save state handshake** — The SVI now waits for a "save state sent" status before exiting the menu
- **Command Center** — Progress bars restored, terminology and output formatting cleaned up, Node.js updated
- **Launcher** — Some UI fixes to the SVI launcher

## Bug Fixes
- Wi-Fi crash where `frame_queue_drain` allocated a 16,517-byte buffer on core 0's 2,048-byte stack
- Core 1 crash while saving Wi-Fi credentials
- Cheat console memory sweep crash and an off-by-one error in the cheat finder
- Protocol failures on slow network connections, and a ping facility error that caused uploads to fail
- Connection-lost detection, and connection errors in the JavaScript implementation
- HDD mount states left stale when the server connection is killed
- `.CAS` autoload causing a Syntax error
- Dump disk reappearing after a long-press boot; long-press boot now boots to the launcher
- Catalog filter not resetting after a long-press boot
- Media state change now triggers properly when loading media into the Pico, so the SVI can react
- Wi-Fi icon misplacement — the VDP address is parked in unused space and the icon repositioned
- HD logo appearing too soon
- Pico `0x0037` menu-exit trap now disarmed before entering the cartridge
- SSID text overflow in the bottom bar, and an erroneous prompt in `server.js`
- Wi-Fi credential write script fixed

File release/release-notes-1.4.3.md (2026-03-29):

# SVI-3x8 PicoExpander v1.4.3 Release Notes

## New Features
- **Hard disk emulation** — Full HDD emulation support, including server-based (network-backed) hard disk emulation
- **Menu launching from keyboard** — Launch menu items directly via keyboard shortcuts (F3 for HDD boot)
- **Media control system** — New doorbell-based media control for managing media ejects, BIOS patching, and data copying between banks
- **SuperExpander adapter PCB** — New adapter board design added
- **Cheat console** — In-system cheat console
- **CP/M 2.27 analysis & tools** — HDD sysgen script, CPM file extractor, disk dumper

## Improvements
- **New memory bank handling** — Completely rewritten memory bank management
- **Reworked boot procedure** — Changed to use ROM cartridge boot from BIOS
- **Wi-Fi stability** — Simplified and stabilized Wi-Fi connection procedure
- **Build system** — Simplified compiling, release firmware stored in Git, cleaned up unused files

## Bug Fixes
- CHGET register corruption fix
- File server file count notification fix
- Flash write comparison fix
- Wi-Fi credential reset no longer clears configuration
- BK4X upload fix
- Various real-hardware fixes

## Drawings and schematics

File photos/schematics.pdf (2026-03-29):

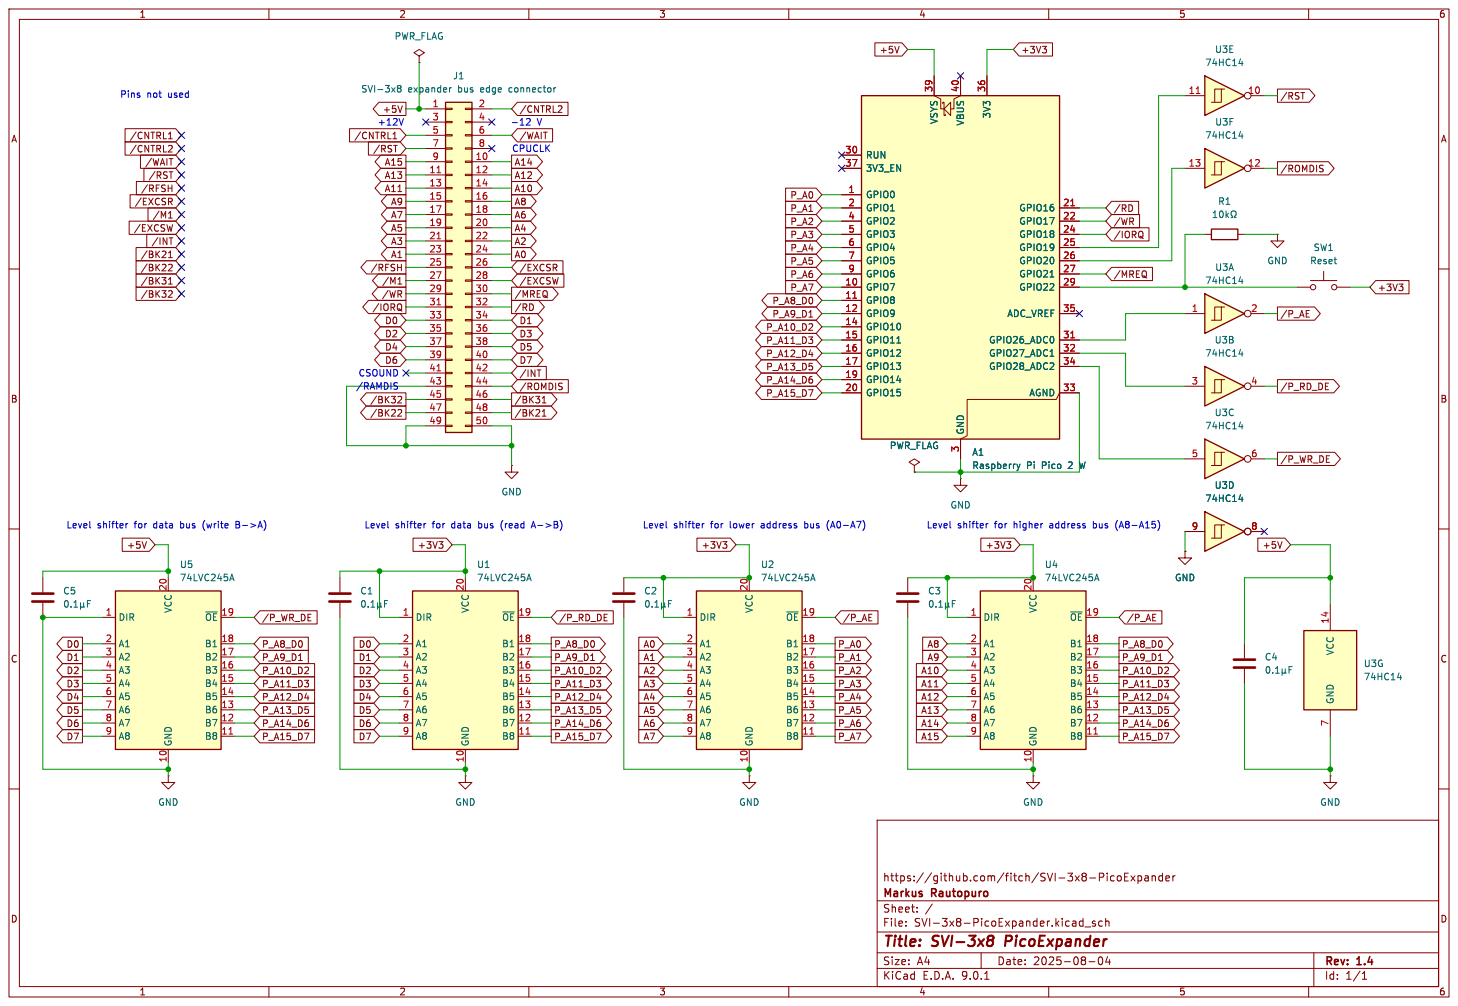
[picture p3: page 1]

3 3V3 36 GPIO16 21 GPIO17 22 GPIO18 24 GPIO19 25 GPIO20 26 GPIO21 27 GPIO22 29 ADC_VREF 35 GPIO26_ADC0 31 GPIO27_ADC1 32 GPIO28_ADC2 34 AGND 33 A1Raspberry Pi Pico 2 W VCC 14 GND

/WAIT
Level shifter for lower address bus (A0-A7) CPUCLK

Level shifter for data bus (read A->B)

https://github.com/fitch/SVI-3x8-PicoExpander

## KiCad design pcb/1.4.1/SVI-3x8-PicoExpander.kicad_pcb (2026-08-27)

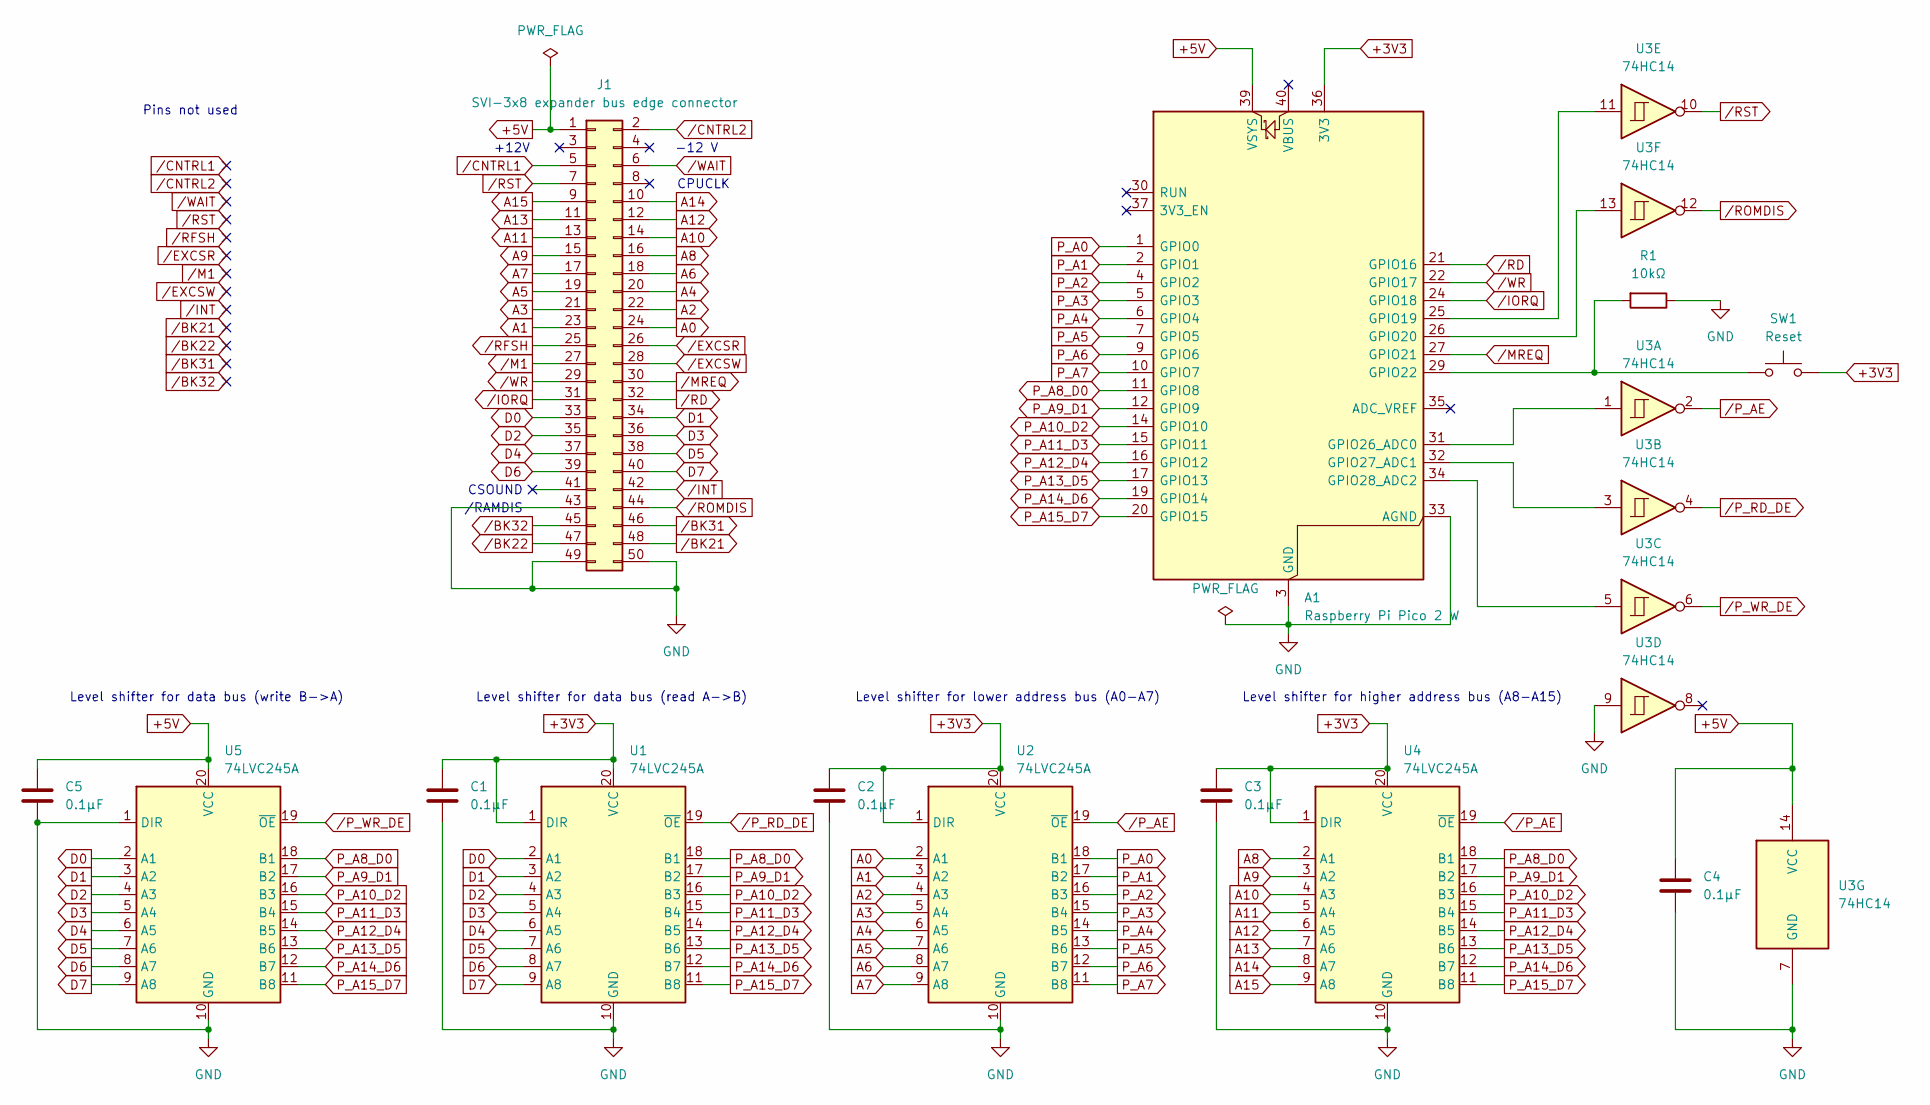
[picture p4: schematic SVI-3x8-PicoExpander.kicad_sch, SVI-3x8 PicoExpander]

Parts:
A1: Raspberry Pi Pico 2 W; RaspberryPi_Pico_Common_Unspecified
C1, C2, C3, C4, C5: 0.1μF; C_Disc_D3.0mm_W1.6mm_P2.50mm
J1: SVI-3x8 expander bus edge connector; DIP-50_EXPANDER_BUS
R1: 10kΩ; R_Axial_DIN0207_L6.3mm_D2.5mm_P7.62mm_Horizontal
SW1: Reset; SW_PUSH_1P1T_6x3.5mm_H4.3_APEM_MJTP1243
U1, U2, U4, U5: 74LVC245A; DIP-20_W7.62mm
U3: 74HC14; DIP-14_W7.62mm

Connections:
+3V3: A1.36 (3V3), C1.1, C2.1, C3.1, SW1.2, U1.1 (DIR), U1.20 (VCC), U2.1 (DIR), U2.20 (VCC), U4.1 (DIR), U4.20 (VCC)
+5V: A1.39 (VSYS), C4.1, C5.1, J1.1, U3.14 (VCC), U5.20 (VCC)
A0: J1.24, U2.2 (A1)
A1: J1.23, U2.3 (A2)
A2: J1.22, U2.4 (A3)
A3: J1.21, U2.5 (A4)
A4: J1.20, U2.6 (A5)
A5: J1.19, U2.7 (A6)
A6: J1.18, U2.8 (A7)
A7: J1.17, U2.9 (A8)
A8: J1.16, U4.2 (A1)
A9: J1.15, U4.3 (A2)
A10: J1.14, U4.4 (A3)
A11: J1.13, U4.5 (A4)
A12: J1.12, U4.6 (A5)
A13: J1.11, U4.7 (A6)
A14: J1.10, U4.8 (A7)
A15: J1.9, U4.9 (A8)
D0: J1.33, U1.2 (A1), U5.2 (A1)
D1: J1.34, U1.3 (A2), U5.3 (A2)
D2: J1.35, U1.4 (A3), U5.4 (A3)
D3: J1.36, U1.5 (A4), U5.5 (A4)
D4: J1.37, U1.6 (A5), U5.6 (A5)
D5: J1.38, U1.7 (A6), U5.7 (A6)
D6: J1.39, U1.8 (A7), U5.8 (A7)
D7: J1.40, U1.9 (A8), U5.9 (A8)
GND: A1.3 (GND), A1.8 (GND), A1.13 (GND), A1.18 (GND), A1.23 (GND), A1.28 (GND), A1.33 (AGND), A1.38 (GND), C1.2, C2.2, C3.2, C4.2, C5.2, J1.43, J1.49, J1.50, R1.1, U1.10 (GND), U2.10 (GND), U3.7 (GND), U3.9, U4.10 (GND), U5.1 (DIR), U5.10 (GND)
unnamed: A1.25 (GPIO19), U3.11
unnamed: A1.26 (GPIO20), U3.13
unnamed: A1.29 (GPIO22), R1.2, SW1.1
unnamed: A1.31 (GPIO26_ADC0), U3.1
unnamed: A1.32 (GPIO27_ADC1), U3.3
unnamed: A1.34 (GPIO28_ADC2), U3.5
P_A0: A1.1 (GPIO0), U2.18 (B1)
P_A1: A1.2 (GPIO1), U2.17 (B2)
P_A2: A1.4 (GPIO2), U2.16 (B3)
P_A3: A1.5 (GPIO3), U2.15 (B4)
P_A4: A1.6 (GPIO4), U2.14 (B5)
P_A5: A1.7 (GPIO5), U2.13 (B6)
P_A6: A1.9 (GPIO6), U2.12 (B7)
P_A7: A1.10 (GPIO7), U2.11 (B8)
P_A8_D0: A1.11 (GPIO8), U1.18 (B1), U4.18 (B1), U5.18 (B1)
P_A9_D1: A1.12 (GPIO9), U1.17 (B2), U4.17 (B2), U5.17 (B2)
P_A10_D2: A1.14 (GPIO10), U1.16 (B3), U4.16 (B3), U5.16 (B3)
P_A11_D3: A1.15 (GPIO11), U1.15 (B4), U4.15 (B4), U5.15 (B4)
P_A12_D4: A1.16 (GPIO12), U1.14 (B5), U4.14 (B5), U5.14 (B5)
P_A13_D5: A1.17 (GPIO13), U1.13 (B6), U4.13 (B6), U5.13 (B6)
P_A14_D6: A1.19 (GPIO14), U1.12 (B7), U4.12 (B7), U5.12 (B7)
P_A15_D7: A1.20 (GPIO15), U1.11 (B8), U4.11 (B8), U5.11 (B8)
/BK21: J1.48
/BK22: J1.47
/BK31: J1.46
/BK32: J1.45
/CNTRL1: J1.5
/CNTRL2: J1.2
/EXCSR: J1.26
/EXCSW: J1.28
/INT: J1.42
/IORQ: A1.24 (GPIO18), J1.31
/M1: J1.27
/MREQ: A1.27 (GPIO21), J1.30
/P_AE: U2.19 (~OE), U3.2, U4.19 (~OE)
/P_RD_DE: U1.19 (~OE), U3.4
/P_WR_DE: U3.6, U5.19 (~OE)
/RD: A1.21 (GPIO16), J1.32
/RFSH: J1.25
/ROMDIS: J1.44, U3.12
/RST: J1.7, U3.10
/WAIT: J1.6
/WR: A1.22 (GPIO17), J1.29

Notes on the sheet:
-12 V
+12V
Level shifter for data bus (read A->B)
CSOUND
Level shifter for data bus (write B->A)
Level shifter for higher address bus (A8-A15)
Level shifter for lower address bus (A0-A7)
CPUCLK
/RAMDIS
Pins not used

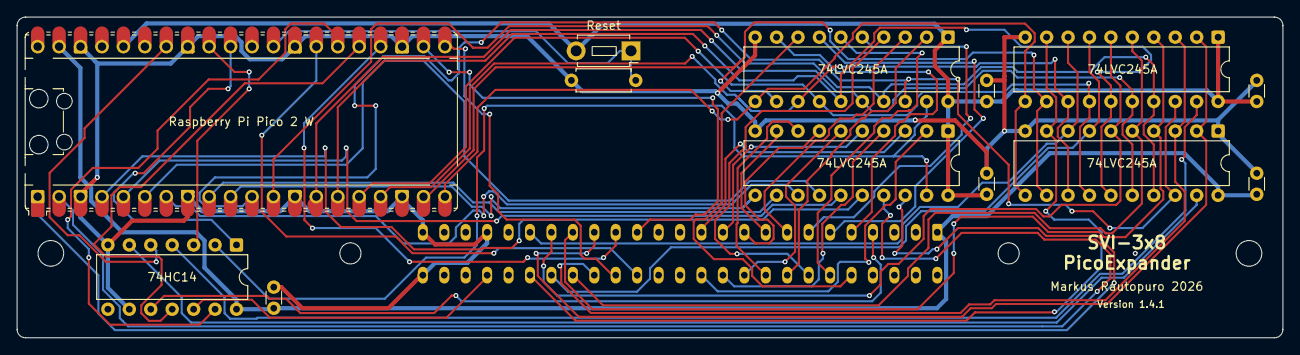
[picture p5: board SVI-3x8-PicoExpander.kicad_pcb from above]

Board: 2 copper layers, 150.0 x 38.0 mm, 14 parts (1 on the bottom side), 58 nets.

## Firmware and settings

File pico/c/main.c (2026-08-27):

/**
 * SVI-3x8 PicoExpander
 * 
 * Copyright (c) 2026 Markus Rautopuro
 * 
 * Works only with Raspberry Pico 2 W.
 */

#include <stdio.h>
#include <string.h>

#include "pico/stdlib.h"
#include "pico/multicore.h"
#include "pico/unique_id.h"
#include "hardware/vreg.h"
#include "hardware/clocks.h"
#include "hardware/flash.h"
#include "wifi.h"
#include "frame.h"
#include "cmd.h"
#include "pico/cyw43_arch.h"
#include "pico/cyw43_driver.h"

#include "svi-328-expander-bus.h"
#include "media_control.h"
#include "log.h"

uint8_t pico_unique_id_chars[2] = {'?', '?'};

void error(int numblink) {
    while (true) {
        for (int i = 0; i < numblink; i++) {
            pico_set_led(true);
            sleep_ms(600);
            pico_set_led(false);
            sleep_ms(500);
        }
        sleep_ms(2000);
    }
}

#define PERSISTED_CONFIG_SIZE 4096
#define PERSISTED_CONFIG_OFFSET 0x3FC000
#define CONFIG_HEADER_MAGIC 0xDEADBEEF

extern const uint8_t __persisted_config[PERSISTED_CONFIG_SIZE];

// Staging buffer for the persisted config sector. Must NOT be a local: core 0's stack
// starts at the bottom of SCRATCH_Y, so a 4 KB frame overflows into SCRATCH_X, which is
// core 1's stack — silently corrupting the bus emulation. Shared by store_config() and
// erase_wifi_credentials(); they never run concurrently.
static uint8_t sector_buf[PERSISTED_CONFIG_SIZE];

int __not_in_flash_func(fetch_config)(void) {
    const uint8_t *stored_config = &__persisted_config[4 + SSID_MAX_LENGTH + PASSWORD_MAX_LENGTH];
    if (memcmp(stored_config, "FLASH", 5) == 0) {
        memcpy((void *)SVI_CONFIG, stored_config, SVI_CONFIG_SIZE);
    }

    if (*(uint32_t *)__persisted_config != CONFIG_HEADER_MAGIC) {
        return PICO_ERROR_GENERIC;
    }

    memcpy((void *)SSID, &__persisted_config[4], SSID_MAX_LENGTH);
    SSID[SSID_MAX_LENGTH] = '\0';

    memcpy((void *)Password, &__persisted_config[4 + SSID_MAX_LENGTH], PASSWORD_MAX_LENGTH);
    Password[PASSWORD_MAX_LENGTH] = '\0';


    log_message("Stored WiFi SSID found: [%s]", SSID);
    log_message("Stored WiFi Password found: [***] (length %zu)", strlen((void *)Password));

    return PICO_OK;
}

int __not_in_flash_func(store_config)(void) {
    memset(sector_buf, 0, sizeof(sector_buf));

    *(uint32_t *)sector_buf = CONFIG_HEADER_MAGIC;
    strncpy((char *)&sector_buf[4], (void *)SSID, SSID_MAX_LENGTH);
    strncpy((char *)&sector_buf[4 + SSID_MAX_LENGTH], (void *)Password, PASSWORD_MAX_LENGTH);
    memcpy(&sector_buf[4 + SSID_MAX_LENGTH + PASSWORD_MAX_LENGTH], (void *)SVI_CONFIG, SVI_CONFIG_SIZE);

    uint32_t ints = save_and_disable_interrupts();
    flash_range_erase(PERSISTED_CONFIG_OFFSET, sizeof(sector_buf));
    flash_range_program(PERSISTED_CONFIG_OFFSET, sector_buf, sizeof(sector_buf));
    restore_interrupts(ints);

    log_message("WiFi credentials stored to flash.");
    return PICO_OK;
}

int __not_in_flash_func(erase_wifi_credentials)(void) {
    memset(sector_buf, 0, sizeof(sector_buf));
    memcpy(&sector_buf[4 + SSID_MAX_LENGTH + PASSWORD_MAX_LENGTH], (void *)SVI_CONFIG, SVI_CONFIG_SIZE);

    uint32_t ints = save_and_disable_interrupts();
    flash_range_erase(PERSISTED_CONFIG_OFFSET, PERSISTED_CONFIG_SIZE);
    flash_range_program(PERSISTED_CONFIG_OFFSET, sector_buf, sizeof(sector_buf));
    restore_interrupts(ints);

    log_message("WiFi credentials erased from flash.");
    return PICO_OK;
}

#define CHECK_INTERVAL_US 500000  // 500 ms in microseconds
static uint32_t last_check_ts;
extern const uint8_t __media_disk[MEDIA_DISK_SIZE];
extern const uint8_t __media_tape[MEDIA_TAPE_SIZE];

int doorbell_fetch_disk_track;
int doorbell_flash_disk_track;
int doorbell_fetch_tape_track;
int doorbell_media_control;
int doorbell_file_server_request;
int doorbell_save_config;
int doorbell_flash_dump_disk;
int doorbell_hdd;

uint8_t disk_flash_buffer[8192]; // Shared buffer: track flash writes AND dump disk double-buffer (2 × 4096)

bool return_to_wifi_credentials = false;
static volatile bool file_server_request_pending = false;

void __not_in_flash_func(core0_doorbell)() {
    // FIXME: The doorbell handler core0_doorbell() runs as an interrupt handler (IRQ). But tcp_write() and tcp_output() are lwIP functions that must run in the main lwIP context (not from an ISR). Calling them from an ISR can corrupt lwIP's internal state
    if (multicore_doorbell_is_set_current_core(doorbell_fetch_disk_track)) {
        uint8_t track = register_track + side * 40;
        uint32_t track_size = track == 0 ? 18 * 128 : 17 * 256;
        uint32_t track_base = track == 0 ? 0 : track * 17 * 256 - 2048;

        memcpy((void *)DISK_TRACK, (void *)(&__media_disk[track_base]), track_size);

        DISK_TRACK_ready = true;           
        multicore_doorbell_clear_current_core(doorbell_fetch_disk_track);
    } else if (multicore_doorbell_is_set_current_core(doorbell_flash_disk_track)) {
        // TODO: REFACTOR - Flash when track is changing AND when disk is shut down

        uint8_t track = register_track + side * 40;
        uint32_t track_size = track == 0 ? 18 * 128 : 17 * 256;
        uint32_t track_base = track == 0 ? 0 : track * 17 * 256 - 2048;

        uint32_t last_boundary = track_base & ~(sizeof(disk_flash_buffer) - 1);
        uint32_t track_offset = track_base - last_boundary;

        memcpy((void *)disk_flash_buffer, (void *)(&__media_disk[last_boundary]), sizeof(disk_flash_buffer));
        memcpy((void *)(&disk_flash_buffer[track_offset]), (void *)DISK_TRACK, track_size);

        uint32_t ints = save_and_disable_interrupts();
        flash_range_erase(MEDIA_DISK_OFFSET + last_boundary, sizeof(disk_flash_buffer));
        flash_range_program(MEDIA_DISK_OFFSET + last_boundary, disk_flash_buffer, sizeof(disk_flash_buffer));
        restore_interrupts(ints);

        write_sector_mode = false;

        DISK_TRACK_ready = true;           
        multicore_doorbell_clear_current_core(doorbell_flash_disk_track);
    } else if (multicore_doorbell_is_set_current_core(doorbell_fetch_tape_track)) {
        memcpy((void *)TAPE_BUFFER, (void *)&__media_tape[tape_index], TAPE_BUFFER_SIZE);
        TAPE_BUFFER_ready = true;
        multicore_doorbell_clear_current_core(doorbell_fetch_tape_track);
    } else if (multicore_doorbell_is_set_current_core(doorbell_media_control)) {
        uint8_t cmd = doorbell_parameter_media_control_command;
        
        if (cmd & 0x80) {
            switch (cmd) {
                case MEDIA_CONTROL_APPLY_BIOS_PATCH:
                    apply_bios_patch();
                    break;
                case MEDIA_CONTROL_REVERT_BIOS_PATCH:
                    revert_bios_patch();
                    break;
            }
        } else {
            if (cmd & MEDIA_CONTROL_EJECT_DISK_0) {
                eject_disk_0();
            }
            if (cmd & MEDIA_CONTROL_EJECT_DISK_1) {
                eject_disk_1();
            }
            if (cmd & MEDIA_CONTROL_EJECT_CARTRIDGE) {
                eject_cartridge();
            }
            if (cmd & MEDIA_CONTROL_EJECT_TAPE) {
                eject_tape();
            }
            if (cmd & MEDIA_CONTROL_LOAD_BK11_TO_CARTRIDGE) {
                load_bk11_to_cartridge();
            }
            if (cmd & MEDIA_CONTROL_LOAD_BOOTSECTOR_TO_CARTRIDGE) {
                load_bootsector_to_cartridge();
            }
        }
        multicore_doorbell_clear_current_core(doorbell_media_control);
        doorbell_parameter_media_control_command = MEDIA_CONTROL_NONE;

    } else if (multicore_doorbell_is_set_current_core(doorbell_file_server_request)) {
        file_server_request_pending = true;
        multicore_doorbell_clear_current_core(doorbell_file_server_request);
    } else if (multicore_doorbell_is_set_current_core(doorbell_save_config)) {
        store_config();
        multicore_doorbell_clear_current_core(doorbell_save_config);
    } else if (multicore_doorbell_is_set_current_core(doorbell_flash_dump_disk)) {
        // Flash one 4096-byte half of the disk_flash_buffer (used as dump disk double-buffer)
        uint32_t half_offset = dump_disk_flash_half * DUMP_DISK_SECTOR_SIZE;

        uint32_t ints = save_and_disable_interrupts();
        flash_range_erase(MEDIA_DISK_OFFSET + dump_disk_flash_offset, DUMP_DISK_SECTOR_SIZE);
        flash_range_program(MEDIA_DISK_OFFSET + dump_disk_flash_offset, &disk_flash_buffer[half_offset], DUMP_DISK_SECTOR_SIZE);
        restore_interrupts(ints);

        dump_disk_flash_offset += DUMP_DISK_SECTOR_SIZE;
        multicore_doorbell_clear_current_core(doorbell_flash_dump_disk);
    } else if (multicore_doorbell_is_set_current_core(doorbell_hdd)) {
        hdd_request_pending = true;
        multicore_doorbell_clear_current_core(doorbell_hdd);
    }
}

int __no_inline_not_in_flash_func(main)() {
    boot_time_us = HW_TIMESTAMP;
    frame_init();
    log_message("Booting...");

    // Generate unique visible ASCII characters from Pico's flash serial number
    pico_unique_board_id_t board_id;
    pico_get_unique_board_id(&board_id);
    uint8_t hash1 = board_id.id[0] ^ board_id.id[2] ^ board_id.id[4] ^ board_id.id[6];
    uint8_t hash2 = board_id.id[1] ^ board_id.id[3] ^ board_id.id[5] ^ board_id.id[7];
    pico_unique_id_chars[0] = (hash1 % 94) + 0x21;
    pico_unique_id_chars[1] = (hash2 % 94) + 0x21;
    log_message("PicoExpander unique ID: %c%c", pico_unique_id_chars[0], pico_unique_id_chars[1]);

    vreg_set_voltage(VREG_VOLTAGE_1_20);
    set_sys_clock_khz(300000, true);
    cyw43_set_pio_clkdiv_int_frac8(4, 0); // Default divisor is 2

    gpio_init_mask(ALL_GPIO_MASK);
    gpio_set_dir_in_masked(ALL_GPIO_MASK);

    gpio_put(P_AE_PIN, 1); // Address read is enabled
    gpio_put(P_RD_DE_PIN, 0); // Data read is disabled
    gpio_put(P_WR_DE_PIN, 0); // Data write is disabled
    gpio_put(ROMDIS_PIN, 1); // Start with built-in BIOS ROM and RAM disabled
    gpio_put(RST_PIN, 0); // Start with /RST high
    gpio_set_dir(P_AE_PIN, GPIO_OUT);
    gpio_set_dir(P_RD_DE_PIN, GPIO_OUT);
    gpio_set_dir(P_WR_DE_PIN, GPIO_OUT);
    gpio_set_dir(ROMDIS_PIN, GPIO_OUT);
    gpio_set_dir(RST_PIN, GPIO_OUT);

    doorbell_fetch_disk_track = multicore_doorbell_claim_unused(0b01, true);
    doorbell_flash_disk_track = multicore_doorbell_claim_unused(0b01, true);
    doorbell_fetch_tape_track = multicore_doorbell_claim_unused(0b01, true);
    doorbell_media_control = multicore_doorbell_claim_unused(0b01, true);
    doorbell_file_server_request = multicore_doorbell_claim_unused(0b01, true);
    doorbell_save_config = multicore_doorbell_claim_unused(0b01, true);
    doorbell_flash_dump_disk = multicore_doorbell_claim_unused(0b01, true);
    doorbell_hdd = multicore_doorbell_claim_unused(0b01, true);

    // FIXME: Not sure if this irq2 != irq1 thing is necessary, but it seems to work
    uint32_t irq1 = multicore_doorbell_irq_num(doorbell_fetch_disk_track);
    irq_set_exclusive_handler(irq1, core0_doorbell);
    irq_set_enabled(irq1, true);

    uint32_t irq2 = multicore_doorbell_irq_num(doorbell_flash_disk_track);
    if (irq2 != irq1) {
        irq_set_exclusive_handler(irq2, core0_doorbell);
        irq_set_enabled(irq2, true);
    }

    uint32_t irq3 = multicore_doorbell_irq_num(doorbell_fetch_tape_track);
    if (irq3 != irq1 || irq3 != irq2) {
        irq_set_exclusive_handler(irq3, core0_doorbell);
        irq_set_enabled(irq3, true);
    }

    uint32_t irq4 = multicore_doorbell_irq_num(doorbell_media_control);
    if (irq4 != irq1 || irq4 != irq2 || irq4 != irq3) {
        irq_set_exclusive_handler(irq4, core0_doorbell);
        irq_set_enabled(irq4, true);
    }

    uint32_t irq5 = multicore_doorbell_irq_num(doorbell_file_server_request);
    if (irq5 != irq1 || irq5 != irq2 || irq5 != irq3 || irq5 != irq4) {
        irq_set_exclusive_handler(irq5, core0_doorbell);
        irq_set_enabled(irq5, true);
    }

    uint32_t irq6 = multicore_doorbell_irq_num(doorbell_save_config);
    if (irq6 != irq1 && irq6 != irq2 && irq6 != irq3 && irq6 != irq4 && irq6 != irq5) {
        irq_set_exclusive_handler(irq6, core0_doorbell);
        irq_set_enabled(irq6, true);
    }

    uint32_t irq7 = multicore_doorbell_irq_num(doorbell_flash_dump_disk);
    if (irq7 != irq1 && irq7 != irq2 && irq7 != irq3 && irq7 != irq4 && irq7 != irq5 && irq7 != irq6) {
        irq_set_exclusive_handler(irq7, core0_doorbell);
        irq_set_enabled(irq7, true);
    }

    uint32_t irq8 = multicore_doorbell_irq_num(doorbell_hdd);
    if (irq8 != irq1 && irq8 != irq2 && irq8 != irq3 && irq8 != irq4 && irq8 != irq5 && irq8 != irq6 && irq8 != irq7) {
        irq_set_exclusive_handler(irq8, core0_doorbell);
        irq_set_enabled(irq8, true);
    }

    multicore_launch_core1(core1_entry);

    wifi_init();
    stdio_usb_init();
    /*
    // FIXME: Warning, don't leave this to production as the core 0 jams here if USB is not connected.
    while (!stdio_usb_connected()) {
        sleep_ms(100);
    }
    */
    
    pico_set_led(true);

    log_message("SVI-3x8 PicoExpander version %s (%s)", VERSION, BUILD_DATE);

    if (fetch_config() != PICO_OK) {
        log_message("No stored WiFi credentials found.");
        log_message("Waiting for WiFi credentials...");

rewait_for_wifi_credentials:
        pico_state = PICO_STATE_WAITING_CREDENTIALS;
        while (pico_state != PICO_STATE_CREDENTIALS_RECEIVED) {
            sleep_ms(10);
        }

        log_message("WiFi SSID received: [%s]", SSID);
        log_message("WiFi Password received: [%s]", Password);

        store_config();
    } 
    pico_state = PICO_STATE_CREDENTIALS_STORED;
    pico_set_led(false);
    pico_state = PICO_STATE_WIFI_CONNECTING;

    log_message("Starting blocking Wi-Fi scan...");
    network_status = NETWORK_STATUS_CONNECTING;
    cyw43_arch_enable_sta_mode();
    int found_ssid_auth_mode = wifi_scan((char *)SSID);

    log_message("Connecting to WiFi SSID [%s]...", SSID);
    uint32_t auth = CYW43_AUTH_WPA2_AES_PSK;
    switch (found_ssid_auth_mode) {
        case 0:
            log_message("SSID auth mode: OPEN");
            auth = CYW43_AUTH_OPEN;
            break;
        case 5:
            log_message("SSID auth mode: WPA2_AES_PSK");
            auth = CYW43_AUTH_WPA2_AES_PSK;
            break;
        case -1:
            log_message("SSID wasn't found in scanning, defaulting to WPA2_AES_PSK");
            break;
        default:
            log_message("SSID auth mode unknown (%d), defaulting to WPA2_AES_PSK", found_ssid_auth_mode);
            break;
    }

    int ret = cyw43_arch_wifi_connect_timeout_ms((char *)SSID, (char *)Password, auth, 30000);
    if (ret != PICO_OK) {
        int blink_count;

        network_status = NETWORK_STATUS_ERROR;
        file_server_status = FILE_SERVER_NOT_CONNECTED;

        log_message("WiFi SSID used: [%s]", SSID);
        log_message("WiFi Password used: [%s]", Password); // FIXME: Warning, will expose password

        switch (ret) {
            case PICO_ERROR_TIMEOUT:
                log_message("WiFi connection timed out.");
                erase_wifi_credentials();

                pico_state = PICO_STATE_WIFI_TIMEOUT;
                log_message("Waiting again for WiFi credentials...");
                goto rewait_for_wifi_credentials; // Retry fetching credentials
                break;
            case PICO_ERROR_BADAUTH:
                log_message("WiFi connection failed due to bad authentication.");
                erase_wifi_credentials();

                pico_state = PICO_STATE_WIFI_BAD_AUTH;
                log_message("Waiting again for WiFi credentials...");
                goto rewait_for_wifi_credentials; // Retry fetching credentials
                break;
            case PICO_ERROR_CONNECT_FAILED:
                log_message("WiFi connection failed.");
                blink_count = 3;
                break; 
            default:
                log_message("WiFi connection failed with unknown error code: %d", ret);
                blink_count = 4;
                break;
        }
        erase_wifi_credentials();
        error(blink_count);
    }

    network_status = NETWORK_STATUS_CONNECTED;

    pico_state = PICO_STATE_WIFI_CONNECTED;
    log_message("WiFi connected to access point.");

    if (cyw43_wifi_pm(&cyw43_state, CYW43_NONE_PM) == 0) {
        log_message("WiFi power-save disabled (PM=NONE).");
    }

    wait_for_ip();
    frame_server_setup();

    last_check_ts = HW_TIMESTAMP;
    bool led_on = true;
    pico_set_led(led_on);

    // FIXME: Do we need to check in this loop if WiFi is still connected?
    while (true) {
        uint32_t now = HW_TIMESTAMP;

        if (return_to_wifi_credentials) {
            return_to_wifi_credentials = false;
            erase_wifi_credentials();
            cyw43_arch_deinit();
            wifi_init();
            network_status = NETWORK_STATUS_NOT_CONNECTED;
            file_server_status = FILE_SERVER_NOT_CONNECTED;

            log_message("Waiting again for WiFi credentials...");
            goto rewait_for_wifi_credentials; // Retry fetching credentials
        }

        if ((uint32_t)(now - last_check_ts) >= CHECK_INTERVAL_US) {
            last_check_ts = now;

            if (!frame_is_connected()) {
                led_on = !led_on;
                pico_set_led(led_on);

                send_udp_broadcast();
            } else {
                if (!led_on) {
                    led_on = true;
                    pico_set_led(led_on);
                }
            }
        }

        if (hdd_request_pending) {
            hdd_request_pending = false;
            if (hdd_op_type == HDD_OP_READ) {
                cmd_hdd_read(hdd_request_lba);
            } else {
                cmd_hdd_write(hdd_request_lba);
            }
        }

        if (file_server_request_pending) {
            file_server_request_pending = false;
            switch (doorbell_parameter_file_server_request_type) {
                case FILE_SERVER_REQUEST_FILE_CHUNK:
                    cmd_send_catalog_get(file_index_request);
                    break;
                case FILE_SERVER_REQUEST_FILE_SEND:
                    cmd_send_file_get(file_index_request);
                    break;
                case FILE_SERVER_REQUEST_SAVE_STATE:
                    cmd_send_save_state();
                    break;
                case FILE_SERVER_REQUEST_SET_FILTER:
                    cmd_send_catalog_filter(file_type_filter);
                    break;
            }
        }

        cyw43_arch_poll();
        frame_queue_drain();
        cmd_save_state_poll();
        cmd_dump_poll();
        sleep_ms(1);
    }
}

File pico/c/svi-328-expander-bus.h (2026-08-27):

/**
 * SVI-3x8 PicoExpander
 * 
 * Copyright (c) 2026 Markus Rautopuro
 * 
 * Works only with Raspberry Pico 2 W.
 */

/*
    A0..A15 -> GPIO0..15
    D0..D7 <-> GPIO8..15

    /RD -> GPIO16
    /WR -> GPIO17
    /IORQ -> GPIO18
    /MREQ -> GPIO21

    RST -> GPIO19 (inverted /RST)
    ROMDIS <- GPIO20 (inverted /ROMDIS)
    Reset button -> GPIO22

    P_AE <- GPIO23 (Enable address line read)
    P_RD_DE <- GPIO24 (Enable data line read)
    P_WR_DE <- GPIO25 (Enable data line write)
*/

#define RD_PIN 16
#define WR_PIN 17
#define IORQ_PIN 18
#define MREQ_PIN 21
#define RST_PIN 19
#define ROMDIS_PIN 20
#define RESET_BUTTON_PIN 22
#define P_AE_PIN 26 // Address read enable, enabled when high
#define P_RD_DE_PIN 27 // Data read enable, enabled when high
#define P_WR_DE_PIN 28 // Data write enable, enabled when high

#define P_AE_GPIO_MASK (1UL << P_AE_PIN)
#define P_RD_DE_GPIO_MASK (1UL << P_RD_DE_PIN)
#define P_WR_DE_GPIO_MASK (1UL << P_WR_DE_PIN)
#define RD_GPIO_MASK (1UL << RD_PIN)
#define WR_GPIO_MASK (1UL << WR_PIN)
#define IORQ_GPIO_MASK (1UL << IORQ_PIN)
#define MREQ_GPIO_MASK (1UL << MREQ_PIN)
#define RST_GPIO_MASK (1UL << RST_PIN)
#define ROMDIS_GPIO_MASK (1UL << ROMDIS_PIN)
#define RESET_BUTTON_GPIO_MASK (1UL << RESET_BUTTON_PIN)

#define OTHER_PIN_MASK (P_AE_GPIO_MASK | P_RD_DE_GPIO_MASK | P_WR_DE_GPIO_MASK | RD_GPIO_MASK | WR_GPIO_MASK | IORQ_GPIO_MASK | MREQ_GPIO_MASK | RST_GPIO_MASK | RESET_BUTTON_GPIO_MASK | ROMDIS_GPIO_MASK)
#define ADDRESS_PIN_MASK ((1UL << 16) - 1)
#define DATA_PIN_MASK (((1UL << 8) - 1) << 8) // Data pins shared with higher address pins in GPIO8..15
#define ALL_GPIO_MASK (ADDRESS_PIN_MASK | OTHER_PIN_MASK)
#define IORQ_PORT_PIN_MASK ((1UL << 8) - 1) // I/O port pins are GPIO0..7

#define SSID_MAX_LENGTH 32
#define PASSWORD_MAX_LENGTH 63
#define SAVE_STATE_FILENAME_MAX_LENGTH 256
#define SVI_CONFIG_SIZE 16

// Memory bank sizes
#define BANK_SIZE 32768
#define RAM4_DUMP_START 0xB000
#define RAM4_DUMP_END 0xF040
#define RAM4_DUMP_SIZE (RAM4_DUMP_END - RAM4_DUMP_START) // 16448 bytes

// Bank configuration bit flags (for save states)
#define BANK_CONFIG_BK01 0x01  // Bit 0: BIOS ROM (always excluded)
#define BANK_CONFIG_BK02 0x02  // Bit 1: RAM0
#define BANK_CONFIG_BK11 0x04  // Bit 2: ROM_CARTRIDGE lower
#define BANK_CONFIG_BK12 0x08  // Bit 3: ROM_CARTRIDGE upper
#define BANK_CONFIG_BK21 0x10  // Bit 4: RAM2 lower
#define BANK_CONFIG_BK22 0x20  // Bit 5: RAM2 upper
#define BANK_CONFIG_BK31 0x40  // Bit 6: RAM3 lower
#define BANK_CONFIG_BK32 0x80  // Bit 7: RAM3 upper

#define PICO_ENABLED 255
#define PICO_DISABLED 0
typedef enum {
    PICO_STATE_WAITING_CREDENTIALS = 100,
    PICO_STATE_CREDENTIALS_RECEIVED = 101,
    PICO_STATE_CREDENTIALS_STORED = 102,
    PICO_STATE_WIFI_CONNECTING = 103,
    PICO_STATE_WIFI_CONNECTED = 104,
    PICO_STATE_WIFI_ERROR = 105,
    PICO_STATE_CLIENT_CONNECTED = 106,
    PICO_STATE_RECEIVING_ROM = 107,
    PICO_STATE_ROM_READY = 108,
    PICO_STATE_RECEIVING_DISK = 109,
    PICO_STATE_DISK_READY = 110,
    PICO_STATE_CLIENT_DISCONNECTED = 112,
    PICO_STATE_RECEIVING_TAPE = 113,
    PICO_STATE_TAPE_READY = 114,
    PICO_STATE_BOOT_BIOS = 115,
    PICO_STATE_RECEIVING_BK4X = 116,
    PICO_STATE_SENDING_BK4X = 118,
    PICO_STATE_RECEIVING_FILE_CHUNK = 119,
    PICO_STATE_SENDING_SAVE_STATE = 120,
    PICO_STATE_SAVE_STATE_SENT = 125,
    PICO_STATE_SENDING_BIOS = 121,
    PICO_STATE_SENDING_DISK = 124,
    PICO_STATE_RECEIVING_SAVE_STATE = 122,
    PICO_STATE_SAVE_STATE_READY = 123,
    PICO_STATE_INJECTING_BOOT = 200,
    PICO_STATE_BOOT_SUCCESS = 201,
    PICO_STATE_WIFI_BAD_AUTH = 230,
    PICO_STATE_WIFI_TIMEOUT = 231,
    PICO_STATE_WIFI_RESET = 232,
    PICO_STATE_BOOT_FAIL = 252,
    PICO_STATE_MEMORY_ERROR = 253,
    PICO_STATE_ERROR = 254,
    PICO_STATE_UNKNOWN = 255
} pico_state_t;

typedef enum {
    INJECT_TYPE_NONE = 0,
    INJECT_TYPE_BOOT = 1,
    INJECT_TYPE_REVERT_CART = 2,
    INJECT_TYPE_REVERT_REGISTER_15 = 3,
    INJECT_TYPE_REVERT_0X90_READ = 4,
    INJECT_TYPE_CAPS_LOCK = 5,
    INJECT_TYPE_PREPARE = 6
} inject_type_t;

typedef enum {
    NETWORK_STATUS_NOT_CONNECTED = 0x00,   // 0b00000000 - Not connected, idle
    NETWORK_STATUS_CONNECTING = 0x01,      // 0b00000001 - Connecting
    NETWORK_STATUS_ERROR = 0x02,           // 0b00000010 - Error connecting
    NETWORK_STATUS_CONNECTED = 0x03        // 0b00000011 - Connected
} network_status_t;

typedef enum {
    FILE_SERVER_NOT_CONNECTED = 0x00,      // 0b00000000 - Not connected
    FILE_SERVER_CONNECTED_NO_LIST = 0x08,  // 0b00001000 - Connected, no file list
    FILE_SERVER_UPDATING_LIST = 0x10,      // 0b00010000 - Busy updating file list
    FILE_SERVER_ACTIVE_IDLE = 0x18,        // 0b00011000 - Active and idle
    FILE_SERVER_SENDING_IMAGE = 0x20,      // 0b00100000 - Busy sending an image
    FILE_SERVER_HAS_UPDATED_LIST = 0x28    // 0b00101000 - Has updated file list available
} file_server_status_t;

typedef enum {
    FILE_SERVER_REQUEST_FILE_CHUNK = 1,
    FILE_SERVER_REQUEST_FILE_SEND = 2,
    FILE_SERVER_REQUEST_SAVE_STATE = 3,
    FILE_SERVER_REQUEST_SET_FILTER = 4
} file_server_request_type_t;

typedef enum {
    MEDIA_CONTROL_NONE = 0x00,
    MEDIA_CONTROL_EJECT_DISK_0 = 0x01,
    MEDIA_CONTROL_EJECT_DISK_1 = 0x02,
    MEDIA_CONTROL_EJECT_CARTRIDGE = 0x04,
    MEDIA_CONTROL_EJECT_TAPE = 0x08,
    MEDIA_CONTROL_LOAD_BK11_TO_CARTRIDGE = 0x10,
    MEDIA_CONTROL_LOAD_BOOTSECTOR_TO_CARTRIDGE = 0x20,
    MEDIA_CONTROL_APPLY_BIOS_PATCH = 0x80,
    MEDIA_CONTROL_REVERT_BIOS_PATCH = 0x81
} media_control_command_t;

typedef enum {
    WRITE_MODE_NONE = 0x00,
    WRITE_MODE_CREDENTIALS = 0x01,
    WRITE_MODE_SAVE_STATE = 0x02,
    WRITE_MODE_TERMINATE = 0x03,
    WRITE_MODE_BIOS = 0x04,
    WRITE_MODE_32KB_ROM = 0x05,
    COMMAND_STOP_SERVING_PREPARE = 0x06,
    COMMAND_DUMP_DISK = 0x07,
    COMMAND_PATCH_BIOS = 0x10,
    COMMAND_REVERT_BIOS = 0x11,
    COMMAND_ERASE_CREDENTIALS = 0x13,
    COMMAND_CLEAR_HARDWARE_LOG = 0x14,
    COMMAND_GET_FILE_COUNT = 0x20,
    COMMAND_GET_FILE_INFORMATION = 0x21,
    COMMAND_REQUEST_FILE_SEND = 0x22,
    COMMAND_DISABLE_SHORT_BOOT_PRESS = 0x30,
    COMMAND_ENABLE_SHORT_BOOT_PRESS = 0x31,
    COMMAND_SET_FILE_TYPE_FILTER = 0x40,
    COMMAND_ACCESS_STORED_CONFIG = 0x50,
    COMMAND_FEATURE_FLAGS = 0x51,
    COMMAND_MEDIA_CONTROL = 0x52
} write_mode_t;

typedef enum {
    FILE_REQUEST_STATUS_NOT_READY = 0x80,
    FILE_REQUEST_STATUS_SUCCESS = 0x00,
    FILE_REQUEST_STATUS_FAILED = 0x01
} file_request_status_t;

void __no_inline_not_in_flash_func(core1_entry)();

extern volatile pico_state_t pico_state;
extern volatile inject_type_t inject_type;

extern volatile network_status_t network_status;
extern volatile file_server_status_t file_server_status;
extern volatile file_server_request_type_t doorbell_parameter_file_server_request_type;
extern volatile media_control_command_t doorbell_parameter_media_control_command;
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

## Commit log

2025-09-02 Initial version
    [SVI-3x8-PicoExpander-B_Cu.gbr, SVI-3x8-PicoExpander-B_Mask.gbr, SVI-3x8-PicoExpander-B_Paste.gbr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]
2026-03-29 Update release 1.4.3
    [SVI-3x8-PicoExpander-B_Cu.gbr, SVI-3x8-PicoExpander-B_Mask.gbr, SVI-3x8-PicoExpander-B_Paste.gbr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]
2026-04-05 Fix the following bugs: .CAS autoload causing Syntax error, Dump disk appearing erroneously on the menu after warm reset, catalog filter not resetting properly after warm reset and some text overflow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
    [svi-328-expander-bus.c]
2026-08-27 Update release 1.4.4
    New realtime protocol replacing the custom 10-byte header protocol,
    streamed logging, PCB 1.4.1, plus memory, Wi-Fi and launcher fixes.
    See release/release-notes-1.4.4.md for the full list.
    The pcb/ tree is restructured so each board revision lives in its
    own directory.
    [SVI-3x8-PicoExpander-1.4.1-BOM.xlsx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]
